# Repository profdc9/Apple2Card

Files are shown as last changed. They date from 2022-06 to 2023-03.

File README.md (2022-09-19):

# Apple II Storage Interface and Arduino Inteface

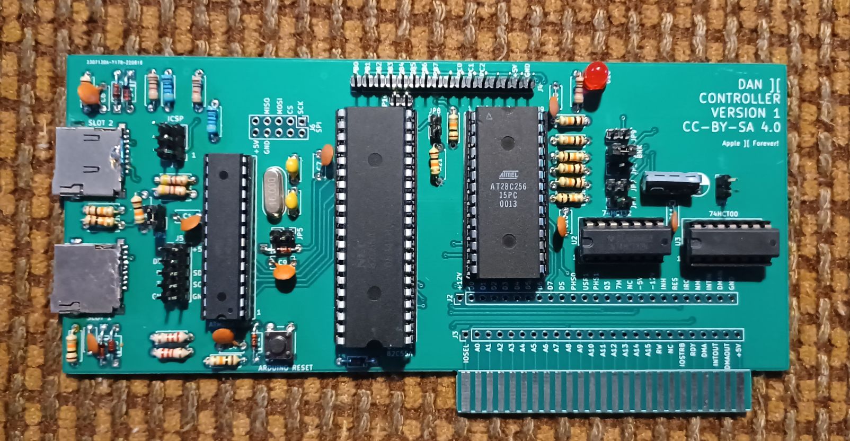
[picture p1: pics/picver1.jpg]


This is a simple card that provides two SD cards as mass storage devices to ProDOS as well as will provide networking using a Wiznet W5500.  A ATMEGA328P programmed using the Arduino development environment is interfaced to the Apple II bus using a 82C55 peripheral interface.  The design uses only five commonly available integrated circuits, the 74HCT08 AND gate, 74HCT32 OR gate, 82C55A peripheral interface, a 28C256 flash memory chip, and a ATMEGA328P microcontroller, and so should be reasonably future-proofed as much as any design for a 40 year old computer can be.

The gerbers for the PCB are in the Apple2Card directly can be made by JLCPCB or PCBway, for example.  The firmware is the "Firmware.bin" file in the Apple2Card directory.  It is a 512 byte file that can be burned onto a 27C128/28C256 flash memory chip using a programmer such as a TL866 plus ii.  Only the first 512 bytes are used of this memory.  The firmware for the ATMEGA328P is the Apple2Arduino sketch in the Apple2Arduino directory.  It should be uploaded using a programmer, however, the bootloader needs to be uploaded first. It should be flashed onto the ATMEGA328P chip without a bootloader.  No SD cards should be present in the SD card slots when the ATMEGA328P is flashed if the ICSP connector on the card is used.  There is a program called FLASH.SYSTEM which can flash the ATMEGA328P on the board.  The jumpers JP2, JP3, JP4, JP6, JP7, JP8, JP9, and JP10 should be closed when flashing with the FLASH.SYSTEM program.  With normal use, all of the jumpers should be open except for JP2 which is closed.

The J1 connector is the ICSP connector for programming the ATMEGA32P.

The J2 and J3 connector break out the bus pins of the Apple II.

The J4 connect are the extra pins of the 82C55 broken out onto a connector.

The J5 connector is for debugging.

The J6 connector is for a Wiznet 5500 SPI ethernet controller (similar to Uthernet).  This has not been implemented yet.

Either micro SD or micro SDHC cards may be used (up to 32 GB capacity), with either FAT16 or FAT32 as the first partition when the FAT filesystem mode is used.  In the raw block mode, only up to the first 512 MB can be used.  To prepare SD cards to be used with storage, you can do it two ways:

The first mode is raw block mode on the SD card.  To use raw block mode, find the "Blankvols.zip" file in the firmware directory.  Unzip this file, and the resulting "Blankvols.PO" file is 512 MB in length.  This can be written to a SD card using an utility such as Win32DiskImager or "dd" under linux.  This is 16 concatenated prepared ProDOS volumes.  Place this in SLOT1 of the card.

The second mode is FAT filesystem mode on the SD card.  A ProDOS order disk image of 32 megabytes can be copied onto the SD card and used.  Such an image is already provided as the file "SingleBlankVol.zip" which is a 32 MB file once unzipped.  Place this file into into the root directory as a file "BLKDEV0X.PO" where X is a digit between 1 and 9.  The default is "1" so for simplicity name it "BLKDEV01.PO".  The ProDOS disk images can be read/written by software such as CiderPress ( https://a2ciderpress.com/ ) so that you can use this to transfer files to and from the Apple II.  Files can be copied onto the ProDOS disk image partition which can then be read/written by CiderPress and transferred to other media.

To make a volume bootable, copy the "PRODOS.SYSTEM" and other system files to be started on booting, for example "BASIC.SYSTEM".

The card can work from any slot, but slot 7 is a good choice so that it can be booted from.  When the card is booted the message "DAN II PRESS RTN" appears on the bottom of the screen.  If the return key is not pressed for a second, then normal booting continues.  The default configuration is to boot the card in SLOT 1 in raw block mode and SLOT 2 in FAT filesystem mode with the filename as "BLKDEV01.PO".

If the return key is pressed during boot up, the following message is shown:

"CARD 1 (0-9,!):"

If in response to this the digit 0 is pressed, the raw block mode is used for SLOT 1.  If digits 1-9 are pressed, FAT filesystem mode is used for SLOT 1, with the filename being "BLKDEV0X.PO" with X being the key pressed.  If ! is pressed, then the mode is wide block mode where both drive 1 and drive 2 of ProDOS are directed to SLOT 1.

Then the next message appears

"CARD 2 (0-9):"

If in response to this the digit 0 is pressed, the raw block mode is used for SLOT 2.  If digits 1-9 are pressed, FAT filsystem mode is used for SLOT 2, with the filename being "BLKDEV0X.PO" with X being the key pressed.  Note that only one of the two slots can be used with FAT filesystem mode at a given time.  If wide block mode is used for CARD 1, then this option does not matter for SLOT 2.

After setting the modes of the two slots, the system continues booting.

Ordinarily, only a maximum of 64 MB is addressable, 32 MB for ProDOS drive 1, and a second 32 MB for ProDOS drive 2.  The program ALLVOLS.SYSTEM allows this limit to be circumvented in ProDOS 8.  For a SD card placed in slot 1, write the image in "BlankVols" or "BlankVolsSlot1"to it, and for a SD card in slot 2, write the image file "BlankVolsSlot2" to it.  When ALLVOLS.SYSTEM is executed, extra volumes may be added from slot 1 or slot 2 depending on if a SD card with block images is present in slot 1 or slot 2.  It is recommended that slot 1 be used for block images and slot 2 be used for FAT FS images.  This way, cards can be swapped in and out of slot 2 with different files transferred from another computer (perhaps using CiderPress) while the boot filesystem in slot 1 stays the same.

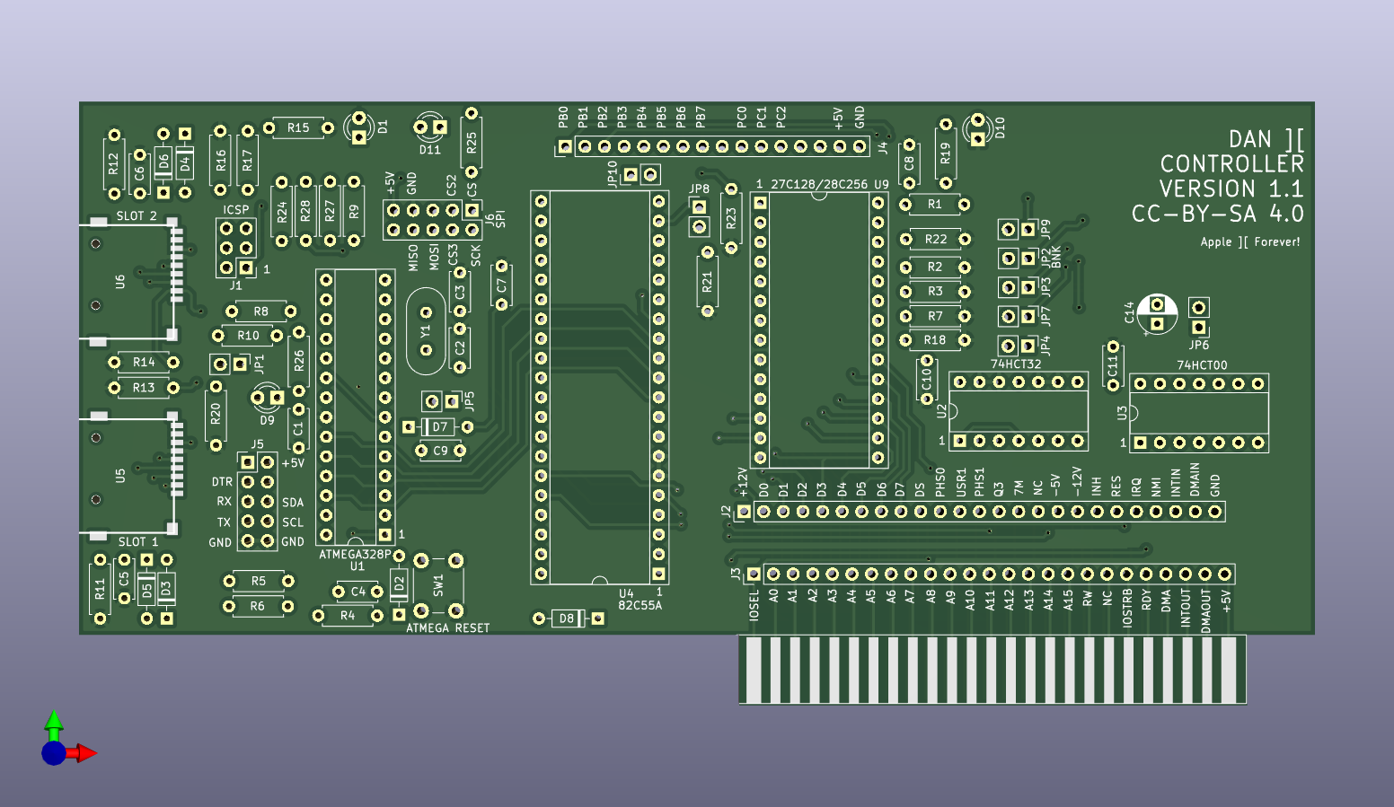
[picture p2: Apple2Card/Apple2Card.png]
Apple2Card


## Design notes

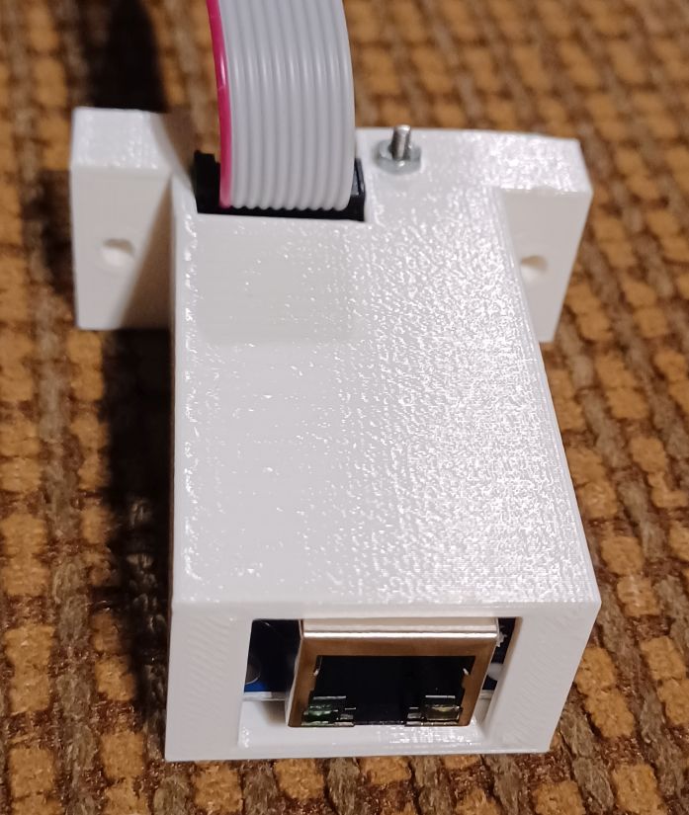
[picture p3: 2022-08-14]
pics/Ethernet-Mount-Front.jpg

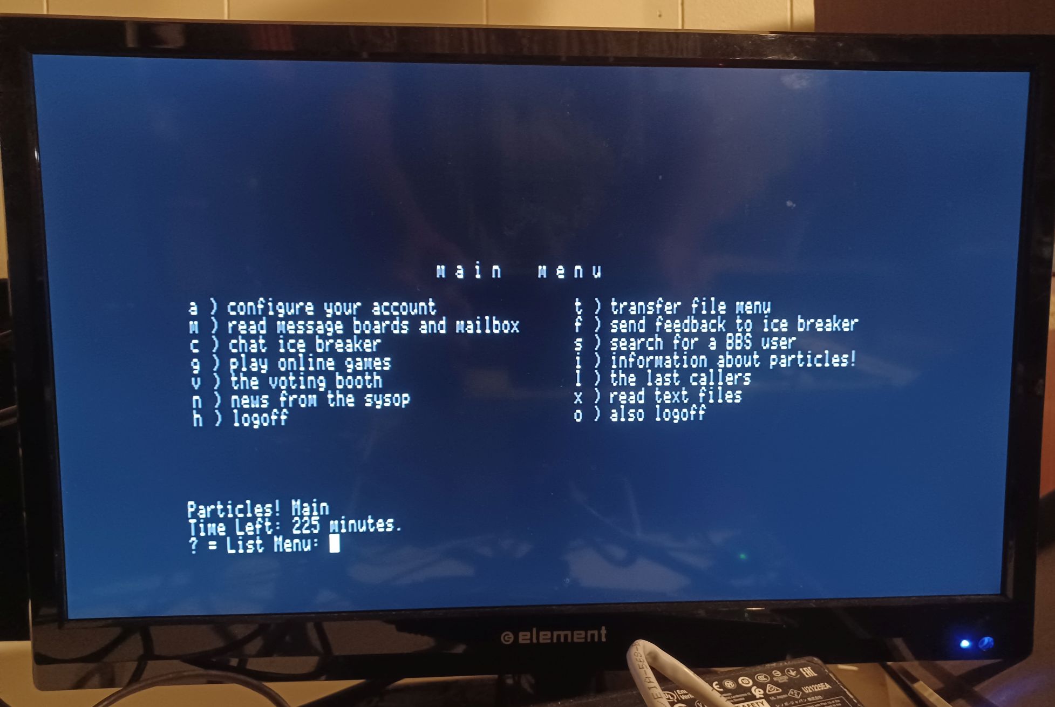
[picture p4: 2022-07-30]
pics/particlesbbs-telnet-example.jpg

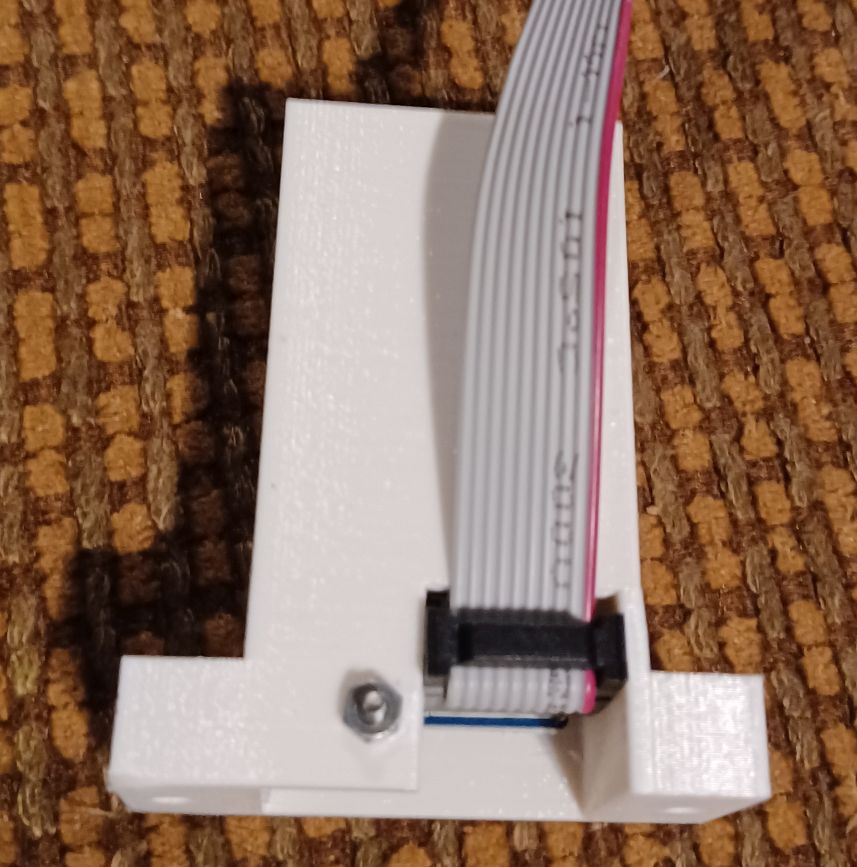
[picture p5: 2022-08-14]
pics/Ethernet-Mount-Back.jpg

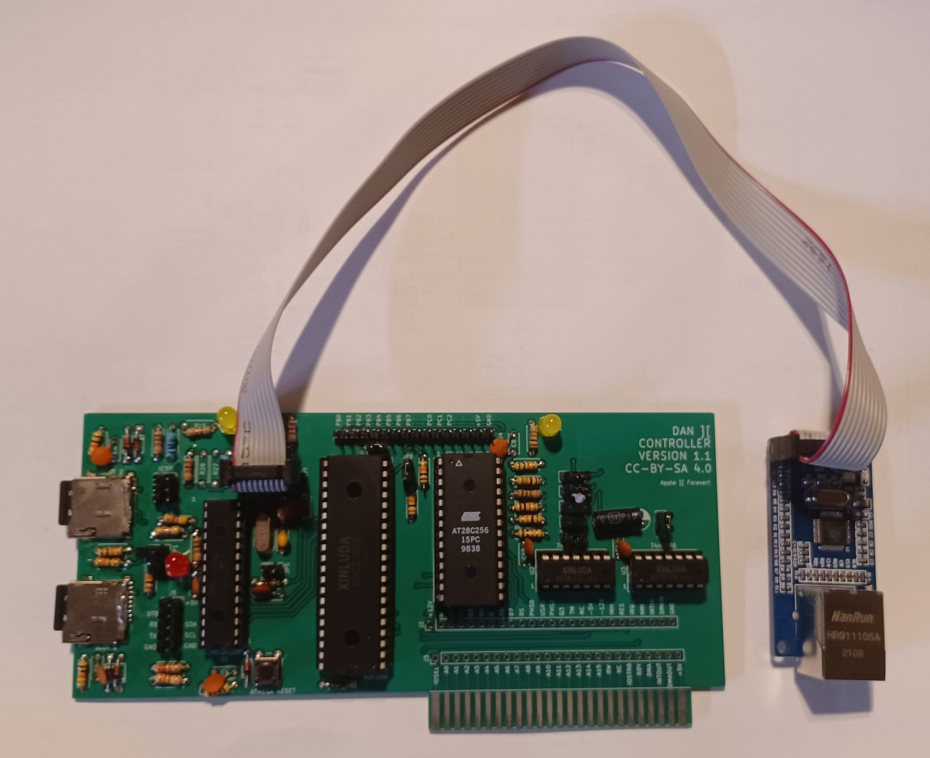
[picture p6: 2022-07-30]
pics/picver11-with-ethernet.jpg

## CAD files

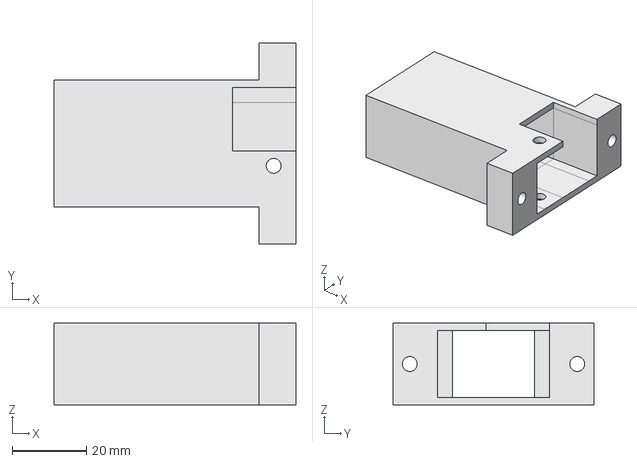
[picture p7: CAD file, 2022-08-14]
CAD/EthernetCover.FCStd
65.0 x 54.0 x 22.0 mm

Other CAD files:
CAD/EthernetCover-EthernetMount.stl

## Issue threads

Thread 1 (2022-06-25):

Build of Materials.

dabonetn, 2022-06-25:
Is there a build of materials with resistor values/sizes, type of sd slot, etc?

profdc9, 2022-06-25:
I have a lcsc.com parts list if you want to look at that.

[ProjectBOM.csv](https://github.com/profdc9/Apple2Card/files/8984833/ProjectBOM.csv)

profdc9, 2022-06-25:
Also here's parts placement
[Parts-Placement.pdf](https://github.com/profdc9/Apple2Card/files/8984834/Parts-Placement.pdf)

dabonetn, 2022-06-30:
I've ordered boards and parts. Hopefully they will show up within a month or so.

msx-solis, 2023-11-29:
Hi,
There are some differences between the current PCB (v1.1) and the schematic, so, even if I generate a new BOM from schematic, fits with your document here but not with the kicad component values on PCB. Witch is the good one?
I mean... I need 2 or 4 x 470R? 3units of 1k or 6 units?
Must we follow what the PCB shows?

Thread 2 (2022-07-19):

Building my first unit, several questions.

dabonetn, 2022-07-19:
Need clarification on some things.

I've got my boards and I've got one nearly built up, and have a few questions.

1. Programming the atmega328p. You say "It should be flashed onto the ATMEGA328P chip without a bootloader. " but the bin file from the audrino output has the name Apple2Arduino.ino.with_bootloader.bin.. Should I just use the hex file named Apple2Arduino.ino.hex??
2. JP2, JP3, JP4 - Should only one of these be selected? What are they actually doing?
3. What jumpers are REQUIRED to run the unit? On the picture I see JP2, JP5 and JP7.
4. What do JP6, JP7, JP8, JP9 and JP10 do? Some seem to control ROM decoding.
5. What are the functions of the LEDs? I think I know, but documentation would be good.
6. Where are the setting stored? On the atmega or the eeprom? (U9)

Thanks!, I'll post more after I get it running over on the vcfed forum.
Keep up the good work.

profdc9, 2022-07-19:
Ok, a number of changes.  I recently revised the board to add some more
functionality.

1.  Program the bootloader first using a programmer.  This sets some fuses
in the ATMEGA328P.  Compile the latest arduino firmware off the project and
upload it using a programmer.  You may need to close JP1 when programming
to power the ATMEGA328P with the programmer if the board is not inside an
apple II when programming.  Make sure there are no SD cards in the slots
whe programming.
2.  The jumpers have changed.  Close jumpers
JP6,JP4,JP7,JP3,JP2,JP9,JP8,JP10.  Then use the "FLASH.SYSTEM" in the
project to flash the firmware onto the FLASH chip.  Then remove the jumpers
except for JP2.  It says this in the "FLASH.SYSTEM" program.
3.  The settings for which drives you are currently using are stored in the
ATMEGA328P EEPROM.  The ROM that the apple ][ sees to boot up is stored in
FLASH rom.
4.  The LEDs are basically convenient access lights to see when the cards
are accessing.  There are two for each card and a third for the planned
network support (W5500).

Dan

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

dabonetn, 2022-07-19:
Is it possible to just program the atmega in the programmer? I've got a tl866 that can handle the chip directly without having to make a programming cable.
I'm also trying to use some standard eproms instead of the eeproms (Out of stock). So what offset does the firmware need to be in the physical chip please. (I have about a 100 27c512s....)

profdc9, 2022-07-19:
You can program the atmega in the programmer but you must set the fuse
values to the standard Arduino fuse values as well as program the firmware.

You can use a 27C512 I believe, as the pinout should be compatible as long
as all the jumpers are open except JP2.  The firmware would be loaded
starting at location zero.

Dan

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

profdc9, 2022-07-19:
Oops, it looks like on the 28C256 the WE line is pin A14 on the 27C512, so
for A14=1, the location to load the firmware at would be $4000, not $0.

Dan

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

dabonetn, 2022-07-20:
Ok, I've got it showing to the apple (Getting the "DAN II PRESS RTN"  prompt).
Using a 8GB generic card that came with one of my 3d printers in slot 2, formatted fat32 and using disk images from www.apple-2.com converted to .po files using cider press, it always breaks to the monitor with

0803-      A=28 X=F8 Y=06 P=35 S=E4.

This is when I select a good disk image number or one that doesn't exist.
I'm slow formatting a 32gb card to try next.

When I tried writing a raw image out with cider press and selecting 0 for the boot, (Card is slot 1), the system just hangs.

profdc9, 2022-07-20:
Format a card FAT32, and then put a 32 MB filesystem on it that is
"BLKDEV01.PO".  Put this card in the lower SD card slot (slot 1).  When you
are booting up, press enter, and then type "1" (for BLKDEV01.PO) for the
first slot, and then choose 0 for the second slot.  Try to see if that
works.

The location it tries to find the image on the card depends on the slot the
card is put into when in mode "0".  This is so many volumes can be accessed
with one card.  The location is at 32 MB X slot number for drive 1, and 32
MB X (slot number + 8) for drive 2.  32 MB = 33554432 bytes exactly.

If you can't get it right, copy the 32 MB file (33554432 byte) file
repeatedly onto the SD card starting at block 0 many times.   If you copy
it 16 times, it will be in all possible locations (all possible slots and
drives).

Dan

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

profdc9, 2022-07-20:
I just tried the original image and the games image from that website, and
they seemed to work ok for e.

Dan

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

dabonetn, 2022-07-20:
I was totally not getting the card 1 and 2 questions.... PLBKAC (Problem lies between keyboard and chair..)

I was trying just slot 2 for the fat32.. I thought slot one was raw sectors.

Just tried 4 of those images and they booted fine.. Total Replay crashes at boot, after displaying the Total Replay text.

Great job.

profdc9, 2022-07-20:
That's weird. I can get Total Replay to work, but only if I boot from
another SD card first, for example, have a mode 0 SD card in slot 1, and
the Replay card in slot 2.

Either slot 1 or slot 2 can be raw sectors which is mode 0 or !  .   If it
is mode 0, the only the slot selected with mode 0 is raw sectors.  If it is
mode ! , both slots are raw sectors from the one SD card that is in SD card
slot 1.  It is possible to assign all of the drivers/sectors to the Dan ][
controller and get over 400 MB in 32 MB volumes.

Dan

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

profdc9, 2022-07-20:
The easy way to do this is to write the Blankvols to a SD card and then
copy the files you want onto the card to make the bootable drive you want.
Blankvols contains 16 consecutive 32 MB filesystems.

Dan

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

dabonetn, 2022-07-20:
""The easy way to do this is to write the Blankvols to a SD card and then
copy the files you want onto the card to make the bootable drive you want.
Blankvols contains 16 consecutive 32 MB filesystems.""

That's a little beyond me, I'm not very experienced with Prodos (Or Apple to be honest.) I was much more of a C64/IBM guy.
How do you boot the other file systems?

Maybe write up a how to? Like start with the most basic instructions and required files and programs?

dabonetn, 2022-07-21:
Ok, another question.. Using both cards, I have images BLKDEV01.PO thtu BLKDEV08.PO files on each.

Booting I select 1 the 2 and boot into a image. (Lets say the booti image), Then if I go into Copy II Plus utils and do a Catalog on slot 7 drive 1, I see the booti drive that I mapped to slot 1, but slot 2 has a read error.

Powering down and swapping cards between the slots results in the same error.

I'm thinking that slot 2 isn't working correctly. Would enabling the debug serial port show any useful information for trouble shooting this?

Thanks, I'm enjoying the learning with this one.

dabonetn, 2022-07-22:
That worked great, now if I only knew how to change partitions using straight prodos on a //e 64k..
Thanks!

profdc9, 2022-07-22:
I'm not sure what you mean with how to change partitions.

It should be possible to change which volumes you are using between boots,
however, I haven't written the program to do that yet...

BTW, Total Replay doesn't seem to have a PRODOS file on it so I don't think
it's bootable in the conventional way.

Dan

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

dabonetn, 2022-07-22:
"" It is possible to assign all of the drivers/sectors to the Dan ][
controller and get over 400 MB in 32 MB volumes""

Ok, by partitions, I meant volumes.. (Sorry, PC guy here..).

"" If ! is pressed, then the mode is wide block mode where both drive 1 and drive 2 of ProDOS are directed to SLOT 1.""

Can you define WIDE block mode better? I used the base BlankVols.po image and put an image in each volume with ciderpress.

profdc9, 2022-07-22:
Ok, so I don't have code to do this yet, but at memory addresses
$BF00-$BFFF (somewhere in there) are the addresses of the driver for each
slot and drive number.  If you choose "0" or "!" and you point the slot and
drive to the driver on the Dan ][ controller, it will use the volume that
is at a given location on the SD card.  So for example, you may not have a
storage device in slot 2, but you could overwrite the address in the table
so that the slot 2 driver goes to the Dan ][ controller and you could get
up to 64 MB (two volumes of 32 MB each for the two drives at that slot)
additional storage.

Yes I know this is not all done yet but honestly even 64 MB is plenty for
most Apple ][ things so it hasn't been a high priority....

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

dabonetn, 2022-07-23:
So I get that I hit ! for wide mode, but for the second question does it matter what you answer for that one?

I'm trying the following sd cards.
4gb
8gb
32gb.

I'm writing out the BlankVols.po image you provided, after I load the partitions.
It always boots the last partition. Either selecting 0 or !.
Selecting ! and a number with no card in slot 2 boots the last partition from the Blankvols.po, and when I hit tab, it lists 7,2
as NEW.DISK.

the 4gb and 8gb were written using Ciderpress.
The 32gb is written using windiskimager.

Doubling up the Blanksvols.po image and writing it to the 32gb still presents NEW.DISK.

dabonetn, 2022-07-27:
Ok, another question for you.

In the wide block mode where both drive 1 and 2 are directed to slot one, where are the boundaries of drives 1 and 2?
I assume since it's block mode, drive 1 starts at sector 0, but how about drive 2?

How many block are presented to the apple when the card is running in block mode per drive?

Thanks.
(p.s. thanks for the quick Total Recall patch!)

profdc9, 2022-07-27:
Sure, when the source of the problem was pointed out it was easy to fix.

The format on the SD card is that each 32 MB volume is a slot and drive, or
65535 blocks + 1 empty block.

The order of the volumes for the first 512 MB of a card:

S0D1 S1D1 S2D1 S3D1 S4D1 S5D1 S6D1 S7D1
S0D2 S1D2 S2D2 S3D2 S4D2 S5D2 S6D2 S7D2

So for example, for S4D2, this would be (11 X 65536 blocks) into the SD
card.

When a "0" mode is used for slot 1, it uses these volumes on the SD card in
slot 1:
S0D1 S1D1 S2D1 S3D1 S4D1 S5D1 S6D1 S7D1

When a "0" mode is used for slot 2, it uses these volumes on the SD card in
slot 2:
S0D2 S1D2 S2D2 S3D2 S4D2 S5D2 S6D2 S7D2

When "!" is used in slot 1, both of the ProDOS drives use slot 1.

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

dabonetn, 2022-07-27:
Ok, I'm now that I'm seeing the layout it making more sense, (like why the S7D1 volume is always the one that boots with the card in slot 7).

But how exactly would you access any slot on the sdcard besides the one that the card is currently in?

I have a test image a test image I wrote out to the card, and I can see S1,S2,S4,S5,S6,and S7 both drives one and two on each, by physically moving the card to the slot number.

This is on a ][e standard 6502, with 64k ram and a old style 80 column card.

I haven't dug out my //gs for testing yet.

profdc9, 2022-07-27:
Well, I plan to make it so that you can copy the driver address to other
slots which don't already have any block devices addressed to them, and
this way you can use the card with many block devices.  I haven't written
the program to do this automatically yet but I have manually tested it.

Dan

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

dabonetn, 2022-07-27:
Ah, ok.

dabonetn, 2022-07-30:
Since all my questions have been answered, I'm closing this.

profdc9, 2022-10-11:
More to the point.... if you look at addresses $BF10-$BF2F in Prodos,
that's where the addresses of the device drivers are.  If you change them
to match the device driver address for the Dan ][, and you have written the
BlankVols.po to the card, it should use the appropriate volume on the card
for the slot and drive.

Dan

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

profdc9, 2022-10-11:
In wide mode,

slot 0 drive 2 starts at sector 8 X 65536 = 524288
slot 1 drive 2 starts at sector 9 X 65536 = 589824
etc...

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

Closed 2022-07-30.

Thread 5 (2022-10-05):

PCB vs schematics: pull-up resistors

ThorstenBr, 2022-10-05:
The PCB wasn't updated when the pull-up resistors were changed from 4k7 to 10k, and from 470 to 4k7 (see commit a848aa25b4dfe19334df68c5f3d26fe0f7ec0768). The current PCB still has the 4k7 / 470 Ohm values. Not a big deal, but a bit confusing. I noticed this since I changed the silk screen of my PCBs to include the component values.

You should update the PCB in KiCad with the latest schematics. Log:

```
Change R3 value from 4k7 to 10k.
Change R18 value from 4k7 to 10k.
Change R2 value from 4k7 to 10k.
Change R21 value from 4k7 to 10k.
Change R22 value from 4k7 to 10k.
Change R28 value from 470R to 4k7.
Change R7 value from 4k7 to 10k.
Change R27 value from 470R to 4k7.
Change R23 value from 4k7 to 10k.
```

ThorstenBr, 2022-10-05:
I created a merge request. You could simply merge this (just the resistor values in the PCB design are updated/changed). Or you can do the update manually (and drop my request).
It's in the KiCad PCB design itself (not the PDF): "Apple2Card.kicad_pcb". If you open the PCB editor to look at the PCB, it was still showing the old resistor values there.

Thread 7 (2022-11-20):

Extended bootloader

ThorstenBr, 2022-11-20:
Hi,
I like the new option to load an extended bootloader from the Arduino flash. We already discussed about this on the Fritter forum. Simply using the existing boot mechanism, and just changing the "Prodos" command is a pretty neat solution.
Are you working on an extended bootloader already or planning to make one?

I did a custom bootloader with a configuration utility for the DAN II card for Apple /// (which did load from an actual boot disk, rather than the DANII controller, since Apple /// doesn't support autoboot ROMs). I could adapt this for the Apple II and make a suggestion (merge request, maybe in a week or two). It could also make use of your new option to read and display the current configuration. Let me know, if you were already working on a bootloader - so I could save the effort.

profdc9, 2022-11-20:
Well, I'm open to having a bootloader written.  Let me explain how it would
have to work and what my idea was, which was very simple.

First what needs to be done.  When you enter the bootloader, the unit
number of the booting device, of which the upper nibble contains the slot
in which it booted from, is in the X register.  Based on this, you can
reconstruct the address of the block routine by using the upper byte as $Cx
where x is the slot number, and the lower byte comes from the location
$CxFF.  You can then store that in the zero page, for example, locations
$F1 (low byte containing contents of $CxFF) and $F2 (high byte containing
$Cx), place the value $20 for the opcode JSR at location $F0, and $60 for
the opcode of RTS at $F3, that way you can JSR $00F0 to call the block
routine.  I have some code below to show how to do this. By the way, I just
changed the "get_status" operation in the Arduino on github, so update
yours before using this code.

My idea for a bootloader was to get the ProDOS volume names of the volume
files on SD slot 1 and SD slot 2 and display them, and then take input for
which was selected.  The ProDOS volume name would serve as the label to
identify the file.

Example code:

INSTRUC = $F0
LOWBT   = $F1
HIGHBT  = $F2
RTSBYT  = $F3
OFFSET  = $F4
VOLDRIVE0 = $F5
VOLDRIVE1 = $F6
BLKBUF = $1000

COMMAND = $42
UNIT    = $43
BUFLO   = $44
BUFHI   = $45
BLKLO   = $46
BLKHI   = $47

START    LDA #$20        ; store JSR at $F0
         STA INSTRUC
         LDA #$60        ; store RTS at $F3
         STA RTSBYT
         STX UNIT        ; store in unit number
         TXA             ; put unit in A register
         LSR A           ; shift to lower nibble
         LSR A
         LSR A
         LSR A
         AND #$07        ; just in case we booted from drive 2 ?
         ORA #$C0        ; make high nibble $C0
         STA HIGHBT      ; store high byte in memory location
         LDY #$00        ; store zero in low byte
         STY LOWBT
         DEY             ; make zero a $FF
         LDA (LOWBT),Y   ; get low byte of address
         STA LOWBT       ; place at low byte
         ...

BUFLOC   LDA #<BLKBUF    ; store buffer location
         STA BUFLO
         LDA #>BLKBUF
         STA BUFHI
         RTS

READB    LDA #$01        ; read block
         STA COMMAND     ; store at $42
         JSR BUFLOC      ; store buffer location
         LDA #$04        ; which block (in this example $0004)
         STA BLKLO
         LDA #$00
         STA BLKHI
         JSR INSTRUC
         RTS

SETVOL   LDA #$06        ; set volume (alternate code)
         STA COMMAND
         JSR BUFLOC      ; dummy buffer location
         LDA VOLDRIVE0
         STA BLKLO
         LDA VOLDRIVE1
         STA BLKHI
         JSR INSTRUC
         RTS

GETVOL   LDA #$05        ; read block
         STA COMMAND     ; store at $42
         JSR BUFLOC      ; store buffer location
         JSR INSTRUC
         LDA BLKBUF
         STA VOLDRIVE0
         LDA BLKBUF+1
         STA VOLDRIVE1
         RTS

REBOOT   LDA #$00        ; store zero byte at $F1
         STA LOWBT
         JMP (LOWBT)     ; jump back and reboot

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

ThorstenBr, 2022-11-21:
Concerning detecting the slot via the X-register: I already had a look into this. Right now, it wouldn't work, since the value of X is lost before the ROM jumps to the bootloader. It always resets X before returning to the caller (or jumping to the bootloader):

```
quitok:
    ldx  unit    ; <<== causes X to be lost prior to "RTS"
    lda  #$00
    clc
    rts
```
The "ldx unit" is probably only required when returning to Prodos, but the same code is executed before jumping to the bootloader. So right now, a bootloader has no way to tell from where it was loaded.

One solution I thought about was making a change to the readbytes routine:
```
@@ -179,8 +179,8 @@ readbytes:
     bne  readbytes   ; get next byte to 256 bytes
     ldy  uppage
     bne  exit512     ; already read upper page
+    stx  uppage      ; store x!=0 to indicate we're processing the second page
     inc  bufhi
-    inc  uppage
     bne  readbytes
```
X is always != 0, so it can be used as a flag to indicate when readbytes is processing the second page (instead of "inc uppage"). As a side effect, the scratch register "uppage" then retains the X value indicating the slot when the bootloader is executed. Tiny change, wouldn't even cost an extra byte.

Ok, I'll be looking into the bootloader. I'll push something to my GitHub when I have a first working version, so you can have a look.

ThorstenBr, 2022-11-21:
Thanks for the hint with the X register and "unit" containing the slot information in the top nibble. I had already looked at that - and initially thought that unit was zero at boot time. So identifying the slot is actually easier than I initially thought.

Ok, I'll be looking into the bootloader. I'll push something to my GitHub when I have a first working version, so you can have a look.

profdc9, 2022-11-22:
I was intending that the unit number would be used to reconstruct the slot
number.  So that for example, if the card was booted from slot 7, unit
number would be $70.  This could be used to reconstruct the address of the
ProDOS block driver routine in $C7xx (where xx is at the location $C7FF).
The code fragment I sent shows how I thought this might be done, so the
code would be consistent with how the bootloader uses the X register.

Dan

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

Closed 2022-11-23.

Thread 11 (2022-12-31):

A2osX Ethernet Driver

burniouf, 2022-12-31:
Where could i find documentation to add an ETH driver to support this board ?

https://github.com/A2osX/A2osX

actually supporting, U1, U2, LANCEGS, SSC/PPP...

https://github.com/A2osX/A2osX/tree/master/DRV

profdc9, 2023-01-01:
Support for ethernet on this board has already been implement on IP65.  It is based on plugging a W5500 Wiznet module into the board via SPI into the ATMEGA328P.  A picture of the board with the ethernet module attached:

https://github.com/profdc9/Apple2Card/blob/main/pics/picver11-with-ethernet.jpg

This is a commonly available W5500 ethernet module.  The IP65 version patched to use the Dan ][ controller with W5500 attached is here:

https://github.com/profdc9/ip65

The file that shows how to communicate with the ATMEGA328P to exchange packets is this one:

https://github.com/profdc9/ip65/blob/main/drivers/dan2d.s

It is pretty simple, as most of the logic to actually control the W5500 is implemented by the ATMEGA328P.   You can ignore the stuff for "ATARI" as it doesn't really apply here.

A command is sending bytes to the 82C55 port A (wrbt) and receiving them (rdbt).

Initialize:
$AC,$10,$XX,$XX,$XX,$XX,$XX,$XX (six bytes of MAC addr to initialize W5500)
receive $00 as confirmation

Poll: (read packet)
$AC,$11,<packet buf size low>,<packet buf size high>
Receive two bytes which is length of packet.  If $00 $00, no packet is available.
Otherwise is low byte, high byte of length of packet
Then receive that number of bytes as the packet

Send:(transmit packet)
$AC,$12,<packet size low>,<packet size high>
Send exact number of packet bytes
Read one byte of result, zero if no error

Hopefully that will get you started.

burniouf, 2023-01-02:
Ok, Perfect! i can quickly write something...
as i have no HW yet to test, could you send me one of your team able to test at :

https://join.slack.com/t/a2osx/shared_invite/zt-ens62cl0-xeAFLjlRfUSMtzdc6o~Xew

is Dan2eth.drv a proper name for this driver ?

profdc9, 2023-01-02:
Dan2eth.drv is just fine as a name for the driver.

profdc9, 2023-01-02:
I don't have any spare cards right now, but I could build one up.  I am
quite busy right now so it might be a little while.  You could get them
faster because there is someone selling them on ebay out of Ireland:

https://www.ebay.com/itm/125663287867

You will also need a W5500 card, this one (available from many vendors):

https://www.ebay.com/itm/311590216566

And a 10 pin IDC (2 rows X 5) 2.54 mm pitch cable to connect the two.

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

burniouf, 2023-01-02:
Ok, thanks... maybe i will order from that guy....

i m almost done writing the DRV.

Any "CLOSE" or "SHUTDOWN" command ?
Any way to get Link Status and 10/100 or HD/FD ?

if someone can test, i will probably get it done today or tomorrow....

burniouf, 2023-01-02:
I would also need a way to detect if WIZ is plugged in....or not....for auto-detection routine.

profdc9, 2023-01-02:
When the initialization occurs, if you do not get a $00, there is an error
initializing.

I don't at present have any close or shutdown commands or link status, I
only implemented what is needed for IP65.

I could look into adding these if it is necessary for A2osX.

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

burniouf, 2023-01-02:
it is not mandatory, but other drivers are written like this :
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

burniouf, 2023-01-02:
DRV done....
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
meet me at SLACK if you want a TEST media

Daniel102010, 2023-01-02:
Hi, I’m Daniel from Ireland , Happy New Year!!! I seen “you’re talking about me “ 😉 if you need one or more Dan II cards you can always contact me directly at ***@***.*** for a better price. Regards Daniel 

Sent from Yahoo Mail for iPhone

On Monday, January 2, 2023, 3:23 p.m., Rémy GIBERT ***@***.***> wrote:

DRV done....

meet me at SLACK if you want a TEST media

—
Reply to this email directly, view it on GitHub, or unsubscribe.
You are receiving this because you are subscribed to this thread.Message ID: ***@***.***>

burniouf, 2023-01-02:
Sure !!

Happy new year!!!

i will contact you at  ***@***.*** with no delay ;-)

Remy

burniouf, 2023-01-04:
Guys, any chance i get a test report about code submitted to Daniel Marks at our SLACK place ?

profdc9, 2023-01-06:
Sorry, I have been very busy the past few days.

I was working on getting the AosX you sent me working.  Unfortunately I can
not use the 800k image you send as I do not have a drive emulator.  It
would be easier if you could send me a zipped 32 MB image file with the
driver to test on it.

Also, having nothing to do with your code, I need to get my wireless
gateway to work in my new location so I can test the ethernet, which I
haven't been able to do yet.  It just won't connect to by router, I need to
figure this out.

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

burniouf, 2023-01-06:
ZIP file & instructions to use it posted at SLACK. enjoy.

profdc9, 2023-01-06:
By the way, how does AosX figure out which slot the Dan ][ card is in?
Does it look for a signature of the ROM?

Dan

On Fri, Jan 6, 2023 at 12:45 AM Rémy GIBERT ***@***.***>
wrote:

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

Micheledipaola, 2023-02-20:
Hey @burniouf and @profdc9 , I have a card assembled by @Daniel102010 and I am very curious about the A2osX driver, since I am waiting for a W5500 module from China. Is it available somewhere? I am wondering also if building a driver for the IIGS could be complicated...

burniouf, 2023-02-20:
hoy @Micheledipaola !
dan2eth.drv Driver is included in most of available A2osX STABLE medias.
An timing issue *may* be still present when running A2osX on IIgs with this driver....still awaiting test reports....
About driver for other TCP/IP stacks, feel free to get the code from A2osX, and of course you can point any other developer to A2osX team if additional information required about supporting this W5500 eth device.

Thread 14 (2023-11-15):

Disk drive still seems to be default device even after image boot

rittwage, 2023-11-15:
I have a weird issue I've noticed with the Dan][.

I have a ProDOS 2.4 image that I've installed GSOS 6.01 on, and it boots into Bitsy.bye normally (I modified the startup to this instead of GSOS/ProDOS). The ProDOS file is renamed to GSOS.

This works fine on my old CF card controller, and on emulators. It boots into Bitsy.Bye and I can choose to boot GSOS or BASIC, or whatever.  However, on the Dan][, it gets an error $002F when you try to boot GSOS.

The weird thing is, if you have a floppy with GSOS in the 3.5 drive, it will boot when you choose the GSOS file on the hard drive.  So, it seems something is pointing the system at the floppy drive instead of the Dan][ partition?

 Card is in slot 7.

The old Apple2.com hard drive image assembled by Vince Briel a while back has a similar problem when booting.

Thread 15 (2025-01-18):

Confusion of the Atmega firmware

coopzone-dc, 2025-01-18:
I have read the README file and just can't work out if I need a chip with the Arduino boot loader installed or not!

It refers to a bootloader install first, but is this the "normal" atmega boot loader, that allows serial upload of the sketch? or what?

What is the correct procedure to put the sketch on the atmega328

Thanks

Derek

profdc9, 2025-01-18:
You can use a chip with the normal bootloader but it is not required.  What
is required is to program the MEGA with the same fuse settings that the
bootloader uses (16 MHz etc.) which I don't remember off the top of my
head, but if you program the bootloader it programs the fuse settings as
well.

Dan

On Sat, Jan 18, 2025 at 10:25 AM coopzone-dc ***@***.***>
wrote:

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

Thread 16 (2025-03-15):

Unable to get the card to work with SD-Card on board

coopzone-dc, 2025-03-15:
Hello,

I have tried all I can think of. I suspect it's a power related problem or a logic level conversion issue.

For example I measured the SD-Card slot voltage at around 3.9v with the two 1n4148's any sd card I try fails 90%+ of the time the other 10% it's very unreliable. I added a 3.3v regulator this helped a little, still fails most of the time.

I have not yet tried different values for the divider resistors 5v to 3.3v conversion. I got side tracked trying a different idea.

I have currently got two SD-Card Arduino mini PCB adaptors connected directly to the atbmega328p. These boards have on board 3.3v regulation and level converters. And They Work!

With these SD-card adaptors I can use the card just fine, once it's been reset CRTL-APPLE-Reset.

The first time you turn the machine on, it still fails and ends up in the Apple monitor. After the press return prompt. At this point if I reset without power off it works fine and keeps working fine until the next power cycle.

I'm happy to use the cards as they work so well. But I was hoping to get, maybe a new version on the sorftware ROM or Atmega with perhaps a delay on power up or an extra reset or something that will stop it failing when powered on?

Has anyone else seen similar issues?

Thanks

Derek

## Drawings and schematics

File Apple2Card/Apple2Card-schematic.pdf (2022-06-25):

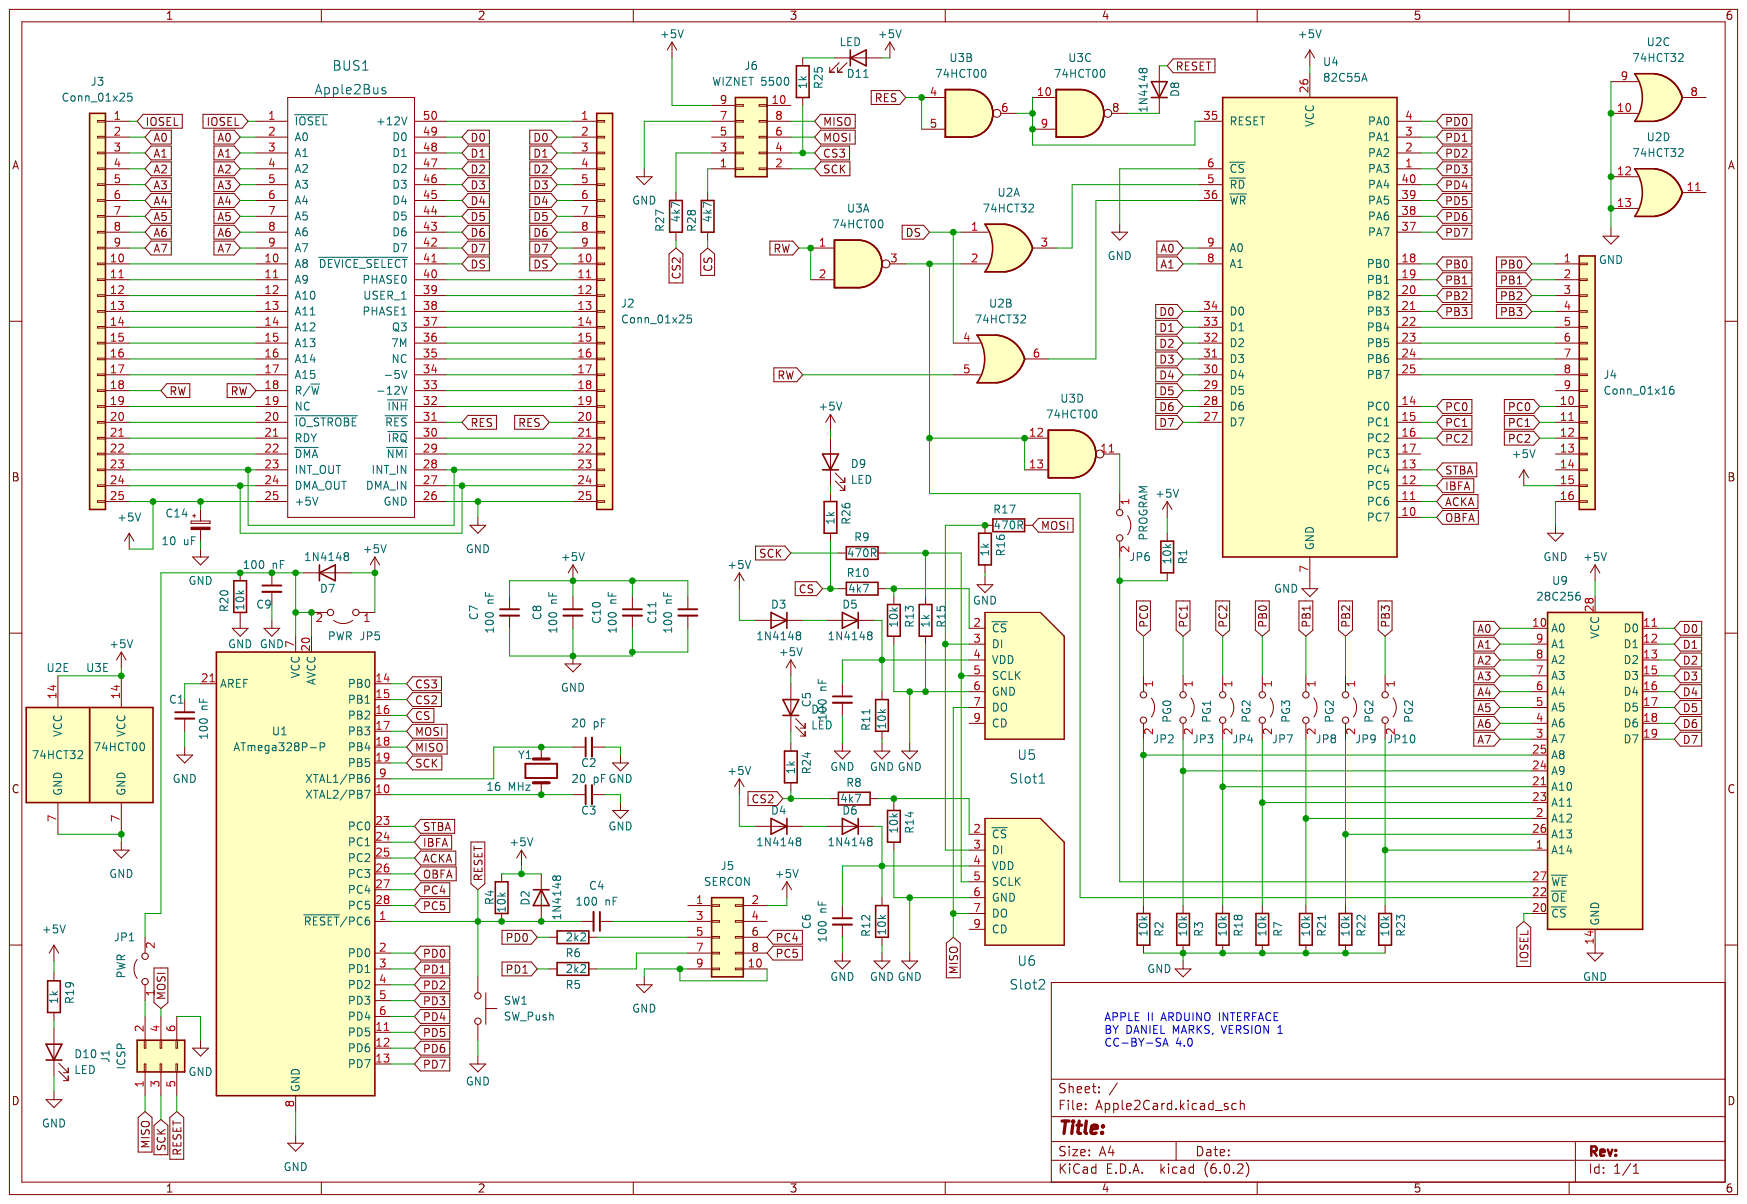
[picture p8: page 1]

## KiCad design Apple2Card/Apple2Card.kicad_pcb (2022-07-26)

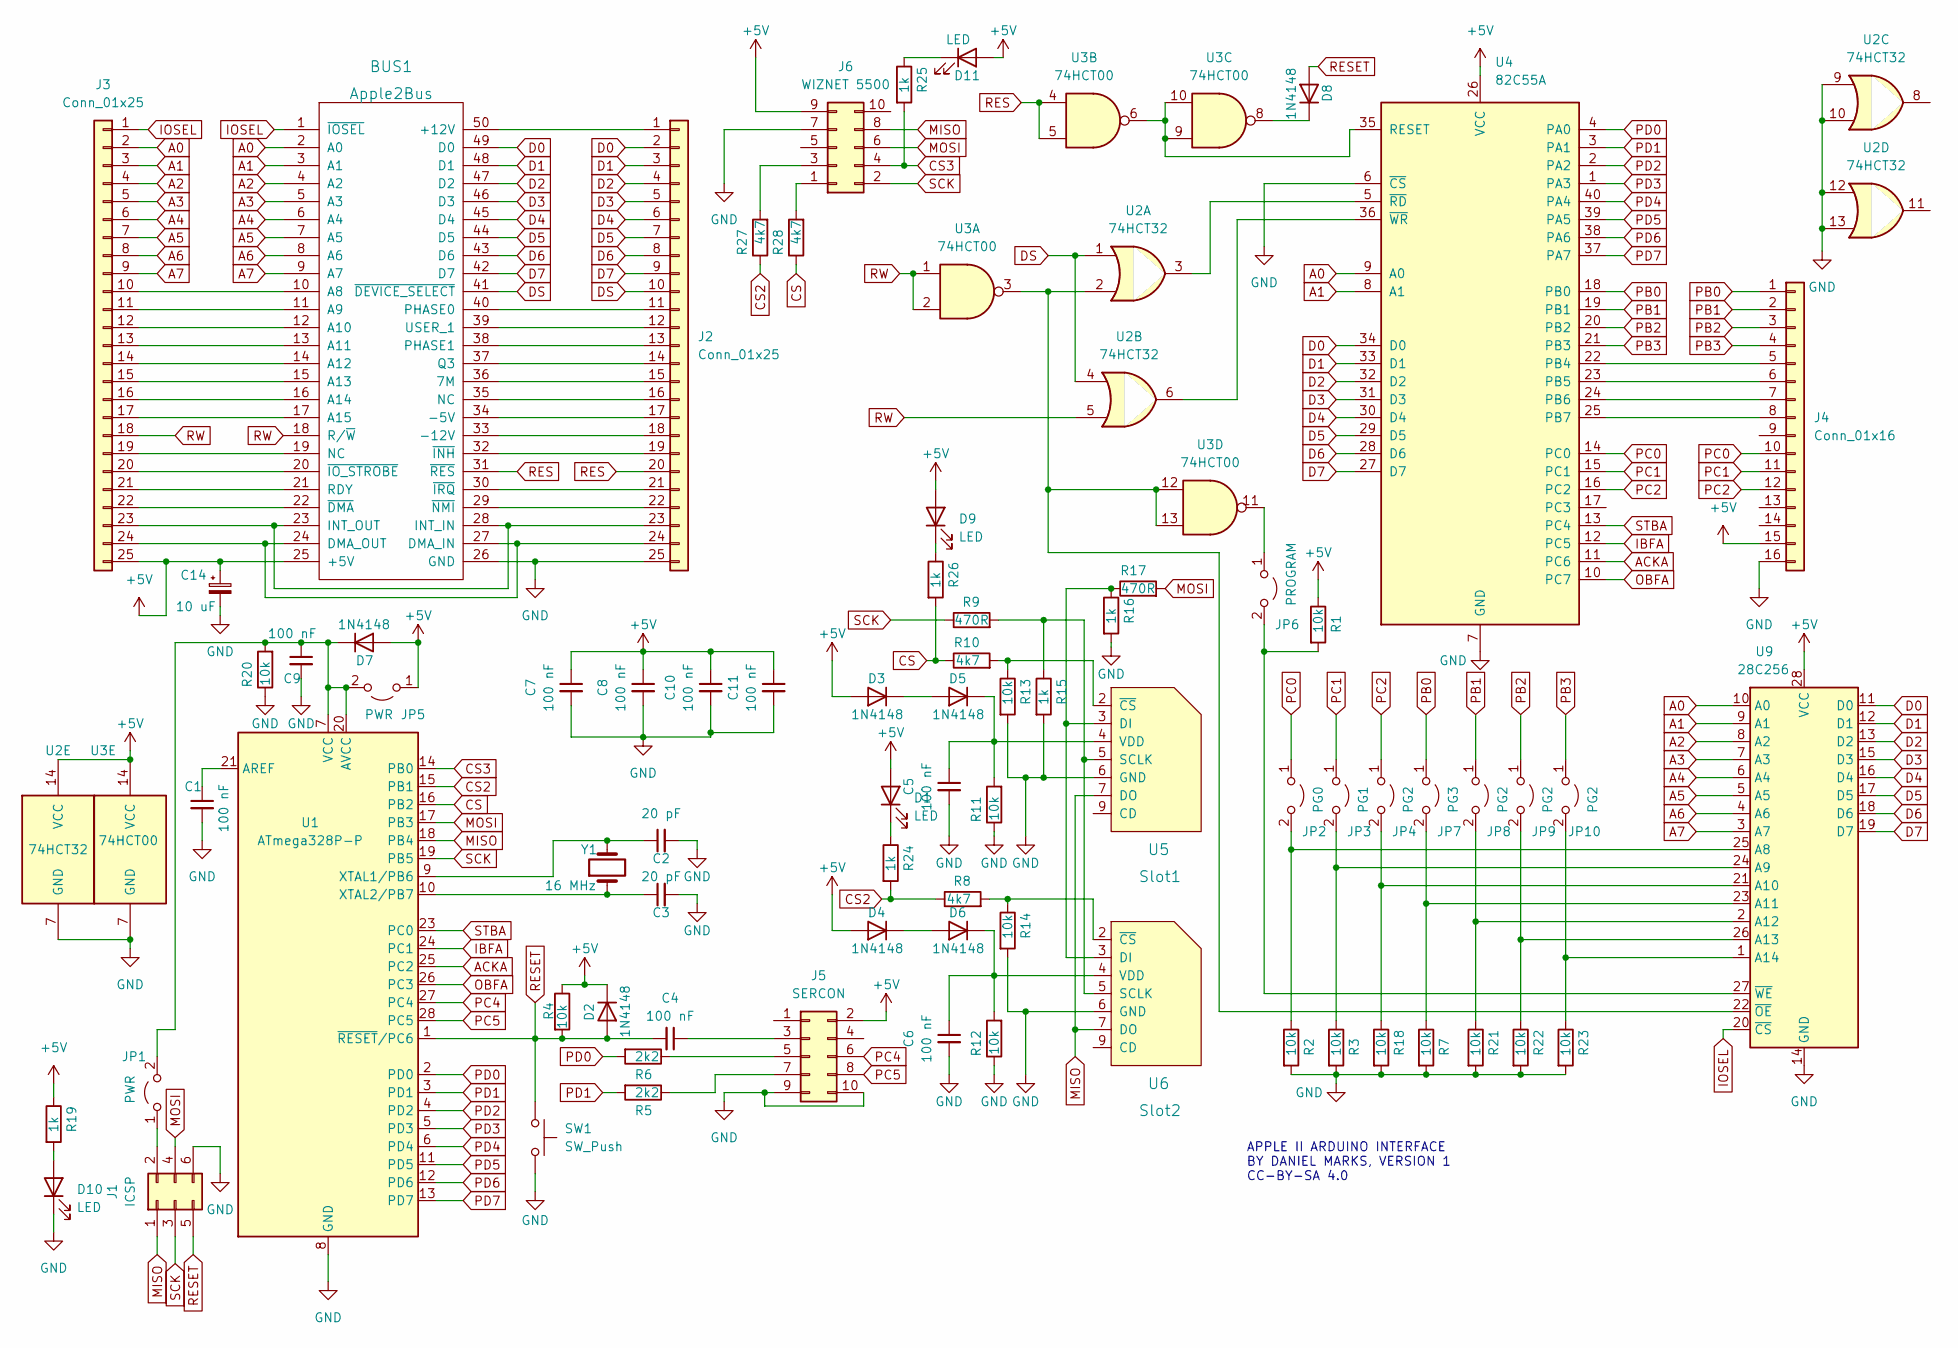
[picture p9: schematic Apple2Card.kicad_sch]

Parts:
BUS1: Apple2Bus; Apple2Slot
C1, C4, C5, C6, C7, C8, C9, C10, C11: 100 nF; C_Disc_D5.0mm_W2.5mm_P5.00mm
C2, C3: 20 pF; C_Disc_D5.0mm_W2.5mm_P5.00mm
C14: 10 uF; CP_Radial_D5.0mm_P2.50mm
D1, D9, D10, D11: LED; LED_D3.0mm
D2, D3, D4, D5, D6, D7, D8: 1N4148; D_DO-35_SOD27_P7.62mm_Horizontal
J1: ICSP; PinHeader_2x03_P2.54mm_Vertical
J2, J3: Conn_01x25; PinHeader_1x25_P2.54mm_Vertical
J4: Conn_01x16; PinHeader_1x16_P2.54mm_Vertical
J5: SERCON; PinHeader_2x05_P2.54mm_Vertical
J6: WIZNET 5500; PinHeader_2x05_P2.54mm_Vertical
JP1, JP5: PWR; PinHeader_1x02_P2.54mm_Vertical
JP2: PG0; PinHeader_1x02_P2.54mm_Vertical
JP3: PG1; PinHeader_1x02_P2.54mm_Vertical
JP4, JP8, JP9, JP10: PG2; PinHeader_1x02_P2.54mm_Vertical
JP6: PROGRAM; PinHeader_1x02_P2.54mm_Vertical
JP7: PG3; PinHeader_1x02_P2.54mm_Vertical
R1, R2, R3, R4, R7, R11, R12, R13, R14, R18, R20, R21, R22, R23: 10k; R_Axial_DIN0207_L6.3mm_D2.5mm_P7.62mm_Horizontal
R5, R6: 2k2; R_Axial_DIN0207_L6.3mm_D2.5mm_P7.62mm_Horizontal
R8, R10, R27, R28: 4k7; R_Axial_DIN0207_L6.3mm_D2.5mm_P7.62mm_Horizontal
R9, R17: 470R; R_Axial_DIN0207_L6.3mm_D2.5mm_P7.62mm_Horizontal
R15, R16, R19, R24, R25, R26: 1k; R_Axial_DIN0207_L6.3mm_D2.5mm_P7.62mm_Horizontal
SW1: SW_Push; SW_PUSH_6mm
U1: ATmega328P-P; DIP-28_W7.62mm_Socket
U2: 74HCT32; DIP-14_W7.62mm_Socket
U3: 74HCT00; DIP-14_W7.62mm_Socket
U4: 82C55A; DIP-40_W15.24mm_Socket
U5: Slot1; GCT-MEM2055-00-190-01-A
U6: Slot2; GCT-MEM2055-00-190-01-A
U9: 28C256; DIP-28_W15.24mm_Socket
Y1: 16 MHz; Crystal_HC49-U_Vertical

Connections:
+5V: BUS1.25 (+5V), C7.1, C8.1, C10.1, C11.1, C14.1, D1.2 (A), D2.1 (K), D3.2 (A), D4.2 (A), D7.2 (A), D9.2 (A), D11.2 (A), J3.25, J4.15, J5.2, J6.9, JP5.1 (A), R1.1, R4.1, R19.1, U2.14 (VCC), U3.14 (VCC), U4.26 (VCC), U9.28 (VCC)
A0: BUS1.2 (A0), J3.2, U4.9 (A0), U9.10 (A0)
A1: BUS1.3 (A1), J3.3, U4.8 (A1), U9.9 (A1)
A2: BUS1.4 (A2), J3.4, U9.8 (A2)
A3: BUS1.5 (A3), J3.5, U9.7 (A3)
A4: BUS1.6 (A4), J3.6, U9.6 (A4)
A5: BUS1.7 (A5), J3.7, U9.5 (A5)
A6: BUS1.8 (A6), J3.8, U9.4 (A6)
A7: BUS1.9 (A7), J3.9, U9.3 (A7)
ACKA: U1.25 (PC2), U4.11 (PC6)
CS: R10.1, R26.2, R28.1, U1.16 (PB2)
CS2: R8.1, R24.2, R27.1, U1.15 (PB1)
CS3: J6.4, R25.2, U1.14 (PB0)
D0: BUS1.49 (D0), J2.2, U4.34 (D0), U9.11 (D0)
D1: BUS1.48 (D1), J2.3, U4.33 (D1), U9.12 (D1)
D2: BUS1.47 (D2), J2.4, U4.32 (D2), U9.13 (D2)
D3: BUS1.46 (D3), J2.5, U4.31 (D3), U9.15 (D3)
D4: BUS1.45 (D4), J2.6, U4.30 (D4), U9.16 (D4)
D5: BUS1.44 (D5), J2.7, U4.29 (D5), U9.17 (D5)
D6: BUS1.43 (D6), J2.8, U4.28 (D6), U9.18 (D6)
D7: BUS1.42 (D7), J2.9, U4.27 (D7), U9.19 (D7)
DS: BUS1.41 (~DEVICE_SELECT), J2.10, U2.1, U2.4
GND: BUS1.26 (GND), C1.2, C2.2, C3.2, C5.2, C6.2, C7.2, C8.2, C9.2, C10.2, C11.2, C14.2, D10.1 (K), J1.6, J2.25, J4.16, J5.9, J5.10, J6.7, R2.2, R3.2, R7.2, R11.1, R12.1, R13.2, R14.2, R15.2, R16.2, R18.2, R20.1, R21.2, R22.2, R23.2, SW1.2, U1.8 (GND), U1.22 (GND), U2.7 (GND), U2.9, U2.10, U2.12, U2.13, U3.7 (GND), U4.6 (~CS), U4.7 (GND), U5.6 (GND), U6.6 (GND), U9.14 (GND)
IBFA: U1.24 (PC1), U4.12 (PC5)
IOSEL: BUS1.1 (~IOSEL), J3.1, U9.20 (~CS)
MISO: J1.1, J6.8, U1.18 (PB4), U5.7 (DO), U6.7 (DO)
MOSI: J1.4, J6.6, R17.2, U1.17 (PB3)
unnamed: BUS1.10 (A8), J3.10
unnamed: BUS1.11 (A9), J3.11
unnamed: BUS1.12 (A10), J3.12
unnamed: BUS1.13 (A11), J3.13
unnamed: BUS1.14 (A12), J3.14
unnamed: BUS1.15 (A13), J3.15
unnamed: BUS1.16 (A14), J3.16
unnamed: BUS1.17 (A15), J3.17
unnamed: BUS1.19 (NC), J3.19
unnamed: BUS1.20 (~IO_STROBE), J3.20
unnamed: BUS1.21 (RDY), J3.21
unnamed: BUS1.22 (~DMA), J3.22
unnamed: BUS1.23 (INT_OUT), BUS1.28 (INT_IN), J2.23, J3.23
unnamed: BUS1.24 (DMA_OUT), BUS1.27 (DMA_IN), J2.24, J3.24
unnamed: BUS1.29 (~NMI), J2.22
unnamed: BUS1.30 (~IRQ), J2.21
unnamed: BUS1.32 (~INH), J2.19
unnamed: BUS1.33 (-12V), J2.18
unnamed: BUS1.34 (-5V), J2.17
unnamed: BUS1.35 (NC), J2.16
unnamed: BUS1.36 (7M), J2.15
unnamed: BUS1.37 (Q3), J2.14
unnamed: BUS1.38 (PHASE1), J2.13
unnamed: BUS1.39 (USER_1), J2.12
unnamed: BUS1.40 (PHASE0), J2.11
unnamed: BUS1.50 (+12V), J2.1
unnamed: C1.1, U1.21 (AREF)
unnamed: C2.1, U1.9 (XTAL1/PB6), Y1.2
unnamed: C3.1, U1.10 (XTAL2/PB7), Y1.1
unnamed: C4.1, J5.3
unnamed: C5.1, D5.1 (K), R11.2, U5.4 (VDD)
unnamed: C6.1, D6.1 (K), R12.2, U6.4 (VDD)
unnamed: C9.1, D7.1 (K), JP1.2 (B), JP5.2 (B), R20.2, U1.7 (VCC), U1.20 (AVCC)
unnamed: D1.1 (K), R24.1
unnamed: D3.1 (K), D5.2 (A)
unnamed: D4.1 (K), D6.2 (A)
unnamed: D8.1 (K), U3.8
unnamed: D9.1 (K), R26.1
unnamed: D10.2 (A), R19.2
unnamed: D11.1 (K), R25.1
unnamed: J1.2, JP1.1 (A)
unnamed: J4.5, U4.22 (PB4)
unnamed: J4.6, U4.23 (PB5)
unnamed: J4.7, U4.24 (PB6)
unnamed: J4.8, U4.25 (PB7)
unnamed: J5.5, R6.1
unnamed: J5.7, R5.1
unnamed: J6.1, R28.2
unnamed: J6.3, R27.2
unnamed: JP2.2 (B), R2.1, U9.25 (A8)
unnamed: JP3.2 (B), R3.1, U9.24 (A9)
unnamed: JP4.2 (B), R18.1, U9.21 (A10)
unnamed: JP6.1 (A), U3.11
unnamed: JP6.2 (B), R1.2, U9.27 (~WE)
unnamed: JP7.2 (B), R7.1, U9.23 (A11)
unnamed: JP8.2 (B), R21.1, U9.2 (A12)
unnamed: JP9.2 (B), R22.1, U9.26 (A13)
unnamed: JP10.2 (B), R23.1, U9.1 (A14)
unnamed: R10.2, R13.1, U5.2 (~CS)
unnamed: R8.2, R14.1, U6.2 (~CS)
unnamed: R9.2, R15.1, U5.5 (SCLK), U6.5 (SCLK)
unnamed: R16.1, R17.1, U5.3 (DI), U6.3 (DI)
unnamed: U2.2, U3.3, U3.12, U3.13, U9.22 (~OE)
unnamed: U2.3, U4.5 (~RD)
unnamed: U2.6, U4.36 (~WR)
unnamed: U3.6, U3.9, U3.10, U4.35 (RESET)
OBFA: U1.26 (PC3), U4.10 (PC7)
PB0: J4.1, JP7.1 (A), U4.18 (PB0)
PB1: J4.2, JP8.1 (A), U4.19 (PB1)
PB2: J4.3, JP9.1 (A), U4.20 (PB2)
PB3: J4.4, JP10.1 (A), U4.21 (PB3)
PC0: J4.10, JP2.1 (A), U4.14 (PC0)
PC1: J4.11, JP3.1 (A), U4.15 (PC1)
PC2: J4.12, JP4.1 (A), U4.16 (PC2)
PC4: J5.6, U1.27 (PC4)
PC5: J5.8, U1.28 (PC5)
PD0: R6.2, U1.2 (PD0), U4.4 (PA0)
PD1: R5.2, U1.3 (PD1), U4.3 (PA1)
PD2: U1.4 (PD2), U4.2 (PA2)
PD3: U1.5 (PD3), U4.1 (PA3)
PD4: U1.6 (PD4), U4.40 (PA4)
PD5: U1.11 (PD5), U4.39 (PA5)
PD6: U1.12 (PD6), U4.38 (PA6)
PD7: U1.13 (PD7), U4.37 (PA7)
RES: BUS1.31 (~RES), J2.20, U3.4, U3.5
RESET: C4.2, D2.2 (A), D8.2 (A), J1.5, R4.2, SW1.1, U1.1 (~RESET/PC6)
RW: BUS1.18 (R/~W), J3.18, U2.5, U3.1, U3.2
SCK: J1.3, J6.2, R9.1, U1.19 (PB5)
STBA: U1.23 (PC0), U4.13 (PC4)

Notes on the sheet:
APPLE II ARDUINO INTERFACE BY DANIEL MARKS, VERSION 1 CC-BY-SA 4.0

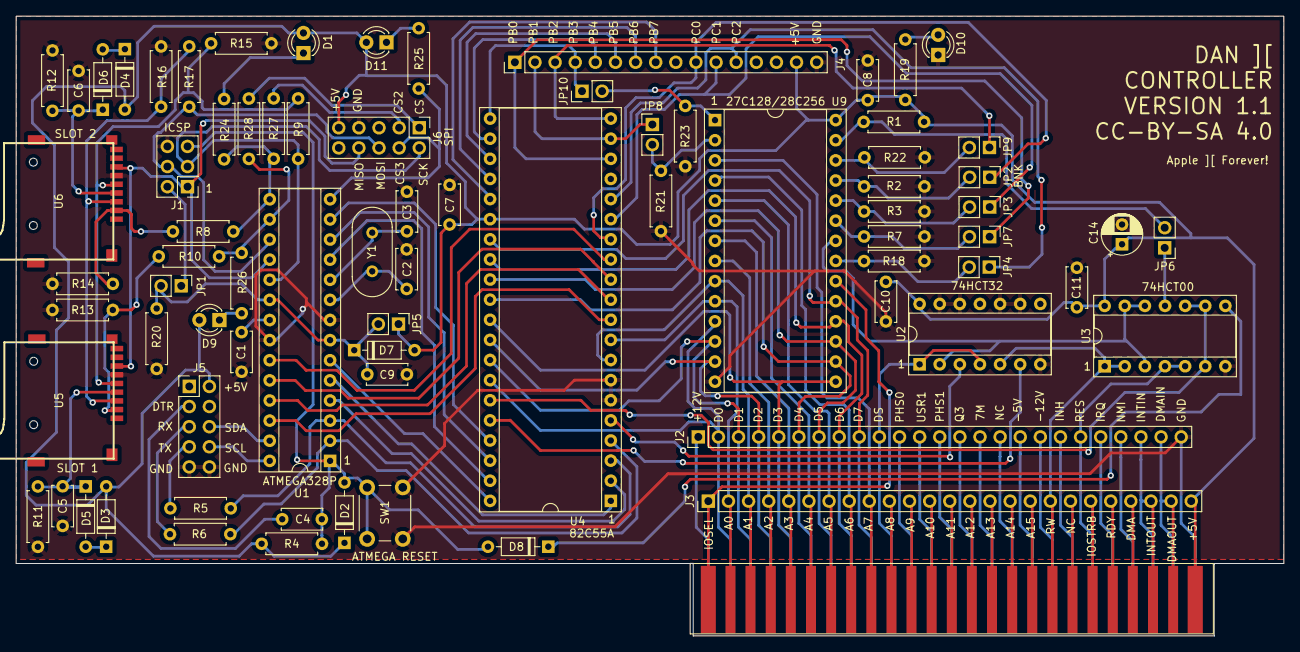
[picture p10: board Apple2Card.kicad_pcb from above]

Board: 2 copper layers, 160.0 x 78.2 mm, 77 parts (0 on the bottom side), 116 nets.

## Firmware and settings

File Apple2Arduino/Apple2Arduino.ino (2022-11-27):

/* Apple2Arduino firmware */
/* by Daniel L. Marks */

/*
   Copyright (c) 2022 Daniel Marks

  This software is provided 'as-is', without any express or implied
  warranty. In no event will the authors be held liable for any damages
  arising from the use of this software.

  Permission is granted to anyone to use this software for any purpose,
  including commercial applications, and to alter it and redistribute it
  freely, subject to the following restrictions:

  1. The origin of this software must not be misrepresented; you must not
   claim that you wrote the original software. If you use this software
   in a product, an acknowledgment in the product documentation would be
   appreciated but is not required.
  2. Altered source versions must be plainly marked as such, and must not be
   misrepresented as being the original software.
  3. This notice may not be removed or altered from any source distribution.
*/

/* Note to self to create objdump:

  C:\Users\dmarks\Documents\ArduinoData\packages\arduino\tools\avr-gcc\4.8.1-arduino5\bin\avr-objdump.exe -x -t -s Apple2Arduino.ino.elf > s155143
*/

#include <Arduino.h>
#include <avr/pgmspace.h>
#include <EEPROM.h>
#include "diskio_sdc.h"
#include "mmc_avr.h"
#include "ff.h"
#include "pindefs.h"

#define USE_ETHERNET
#undef DEBUG_SERIAL

#ifdef USE_ETHERNET
#include "w5500.h"
#endif

#ifdef DEBUG_SERIAL
#include <SoftwareSerial.h>
SoftwareSerial softSerial(SOFTWARE_SERIAL_RX, SOFTWARE_SERIAL_TX);
#define SERIALPORT() (&softSerial)
#endif

#define EEPROM_INIT 0
#define EEPROM_SLOT0 1
#define EEPROM_SLOT1 2

#define SLOT_STATE_NODEV 0
#define SLOT_STATE_BLOCKDEV 1
#define SLOT_STATE_WIDEDEV 2
#define SLOT_STATE_FILEDEV 3

#ifdef USE_ETHERNET
uint8_t ethernet_initialized = 0;
Wiznet5500 eth(8);
#endif

FATFS   fs;
FIL     slotfile;
uint8_t last_drive = 255;

uint8_t slot0_state = SLOT_STATE_NODEV;
uint8_t slot0_fileno;

uint8_t slot1_state = SLOT_STATE_NODEV;
uint8_t slot1_fileno;

static char blockvolzero[] = "0:";
static char blockvolone[] = "1:";

static char blockdev0_filename[] = "0:BLKDEVXX.PO";
static char blockdev1_filename[] = "1:BLKDEVXX.PO";

extern "C" {
  void write_string(const char *c)
  {
#ifdef DEBUG_SERIAL
    SERIALPORT()->print(c);
    SERIALPORT()->flush();
#endif
  }
}

void read_eeprom(void)
{
  if (EEPROM.read(EEPROM_INIT) != 255)
  {
    slot0_fileno = EEPROM.read(EEPROM_SLOT0);
    slot1_fileno = EEPROM.read(EEPROM_SLOT1);
  } else
  {
    slot0_fileno = 0;
    slot1_fileno = 1;
  }
}

void write_eeprom(void)
{
  if (EEPROM.read(EEPROM_SLOT0) != slot0_fileno)
    EEPROM.write(EEPROM_SLOT0, slot0_fileno);
  if (EEPROM.read(EEPROM_SLOT1) != slot1_fileno)
    EEPROM.write(EEPROM_SLOT1, slot1_fileno);
  if (EEPROM.read(EEPROM_INIT) == 255)
    EEPROM.write(EEPROM_INIT, 0);
}

void setup_pins(void)
{
  INITIALIZE_CONTROL_PORT();
  DISABLE_RXTX_PINS();
  DATAPORT_MODE_RECEIVE();
}

void setup_serial(void)
{
  Serial.end();
  DISABLE_RXTX_PINS();
#ifdef DEBUG_SERIAL
#ifdef SOFTWARE_SERIAL
  softSerial.begin(9600);
  pinMode(SOFTWARE_SERIAL_RX, INPUT);
  pinMode(SOFTWARE_SERIAL_TX, OUTPUT);
#endif
#endif
}

void write_dataport(uint8_t ch)
{
  while (READ_IBFA() != 0);
  DATAPORT_MODE_TRANS();
  WRITE_DATAPORT(ch);
  STB_LOW();
  STB_HIGH();
  DATAPORT_MODE_RECEIVE();
}

uint8_t read_dataport(void)
{
  uint8_t byt;

  while (READ_OBFA() != 0);
  ACK_LOW();
  byt = READ_DATAPORT();
  ACK_HIGH();
  return byt;
}

static uint8_t unit;
static uint16_t buf;
static uint16_t blk;

void get_unit_buf_blk(void)
{
  unit = read_dataport();
#ifdef DEBUG_SERIAL
  SERIALPORT()->print("0000 unit=");
  SERIALPORT()->println(unit, HEX);
#endif
  buf = read_dataport();
  buf |= (((uint16_t)read_dataport()) << 8);
#ifdef DEBUG_SERIAL
  SERIALPORT()->print("0000 buf=");
  SERIALPORT()->println(buf, HEX);
#endif
  blk = read_dataport();
  blk |= (((uint16_t)read_dataport()) << 8);
#ifdef DEBUG_SERIAL
  SERIALPORT()->print("0000 blk=");
  SERIALPORT()->println(blk, HEX);
#endif
}

uint8_t hex_digit(uint8_t ch)
{
  if (ch < 10) return ch + '0';
  return ch - 10 + 'A';
}

void set_blockdev_filename(char *blockdev_filename, uint8_t fileno)
{
  blockdev_filename[8] = hex_digit(fileno >> 4);
  blockdev_filename[9] = hex_digit(fileno & 0x0F);
}

uint8_t check_change_filesystem(uint8_t current_filesystem)
{
  if (last_drive == current_filesystem)
    return 1;

  if (last_drive < 2)
  {
    f_close(&slotfile);
    f_unmount(last_drive == 0 ? blockvolzero : blockvolone);
  }
  last_drive = 255;
  if (current_filesystem < 2)
  {
    if (f_mount(&fs, current_filesystem == 0 ? blockvolzero : blockvolone, 0) != FR_OK)
      return 0;
    if (f_open(&slotfile, current_filesystem == 0 ? blockdev0_filename : blockdev1_filename, FA_READ | FA_WRITE) != FR_OK)
    {
      f_unmount(current_filesystem == 0 ? blockvolzero : blockvolone);
      return 0;
    }
  }
  last_drive = current_filesystem;
  return 1;
}

void initialize_drive(void)
{
  if (unit & 0x80)
  {
    if (slot1_state == SLOT_STATE_NODEV)
    {
      if (slot1_fileno == 255)
      {
        if (slot0_state == SLOT_STATE_NODEV)
        {
          if (disk_initialize(0) == 0)
            slot0_state = slot1_state = SLOT_STATE_WIDEDEV;
        }
      } else if (slot1_fileno == 0)
      {
        if (disk_initialize(1) == 0)
          slot1_state = SLOT_STATE_BLOCKDEV;
      } else
      {
        check_change_filesystem(255);
        set_blockdev_filename(blockdev1_filename, slot1_fileno);
        if (check_change_filesystem(1))
          slot1_state = SLOT_STATE_FILEDEV;
      }
    }
  } else
  {
    if (slot0_state == SLOT_STATE_NODEV)
    {
      if (slot0_fileno == 255)
      {
        if (slot1_state == SLOT_STATE_NODEV)
        {
          if (disk_initialize(0) == 0)
            slot0_state = slot1_state = SLOT_STATE_WIDEDEV;
        }
      } else if (slot0_fileno == 0)
      {
        if (disk_initialize(0) == 0)
          slot0_state = SLOT_STATE_BLOCKDEV;
      } else
      {
        check_change_filesystem(255);
        set_blockdev_filename(blockdev0_filename, slot0_fileno);
        if (check_change_filesystem(0))
          slot0_state = SLOT_STATE_FILEDEV;
      }
    }
  }
}

void unmount_drive(void)
{
  if (unit & 0x80)
  {
    switch (slot1_state)
    {
      case SLOT_STATE_NODEV:
        return;
      case SLOT_STATE_WIDEDEV:
      case SLOT_STATE_BLOCKDEV:
        slot1_state = SLOT_STATE_NODEV;
        return;
      case SLOT_STATE_FILEDEV:
        check_change_filesystem(255);
        slot1_state = SLOT_STATE_NODEV;
        return;
    }
  } else
  {
    switch (slot0_state)
    {
      case SLOT_STATE_NODEV:
        return;
      case SLOT_STATE_WIDEDEV:
      case SLOT_STATE_BLOCKDEV:
        slot0_state = SLOT_STATE_NODEV;
        return;
      case SLOT_STATE_FILEDEV:
        check_change_filesystem(255);
        slot0_state = SLOT_STATE_NODEV;
        return;
    }
  }
}

uint8_t check_unit_nodev(void)
{
  if (unit & 0x80)
  {
    if (slot1_state == SLOT_STATE_NODEV)
    {
      write_dataport(0x28);
      return 0;
    }
  } else
  {
    if (slot0_state == SLOT_STATE_NODEV)
    {
      write_dataport(0x28);
      return 0;
    }
  }
  return 1;
}

void do_status(void)
{
  get_unit_buf_blk();
  if (check_unit_nodev())
    write_dataport(0x00);
}

static uint32_t blockloc;

uint32_t calculate_block_location(uint8_t voltype)
{
  uint8_t unitshift = unit & ((voltype == SLOT_STATE_WIDEDEV) ? 0xF0 : 0x70);
  blockloc = ((uint32_t)blk) | (((uint32_t)(unitshift)) << 12);
}

uint32_t calculate_file_location(void)
{
  blockloc = ((uint32_t)blk) << 9;
}

void do_read(void)
{
  UINT br;
  uint8_t buf[512];

  get_unit_buf_blk();
  if (check_unit_nodev() == 0) return;
  if (unit & 0x80)
  {
    switch (slot1_state)
    {
      case SLOT_STATE_WIDEDEV:
      case SLOT_STATE_BLOCKDEV:
        calculate_block_location(slot1_state);
        if (disk_read(slot1_state == SLOT_STATE_BLOCKDEV ? 1 : 0, buf, blockloc, 1) != 0)
        {
          write_dataport(0x27);
          return;
        }
        break;
      case SLOT_STATE_FILEDEV:
        if (!check_change_filesystem(1))
        {
          write_dataport(0x27);
          return;
        }
        calculate_file_location();
        if ((f_lseek(&slotfile, blockloc) != FR_OK) ||
            (f_read(&slotfile, buf, 512, &br) != FR_OK) ||
            (br != 512))
        {
          write_dataport(0x27);
          return;
        }
        break;
    }
  } else
  {
    switch (slot0_state)
    {
      case SLOT_STATE_WIDEDEV:
      case SLOT_STATE_BLOCKDEV:
        calculate_block_location(slot0_state);
        if (disk_read(0, buf, blockloc, 1) != 0)
        {
          write_dataport(0x27);
          return;
        }
        break;
      case SLOT_STATE_FILEDEV:
        if (!check_change_filesystem(0))
        {
          write_dataport(0x27);
          return;
        }
        calculate_file_location();
        if ((f_lseek(&slotfile, blockloc) != FR_OK) ||
            (f_read(&slotfile, buf, 512, &br) != FR_OK) ||
            (br != 512))
        {
          write_dataport(0x27);
          return;
        }
        break;
    }
  }
  write_dataport(0x00);
  DATAPORT_MODE_TRANS();
  for (uint16_t i = 0; i < 512; i++)
  {
    while (READ_IBFA() != 0);
    WRITE_DATAPORT(buf[i]);
    STB_LOW();
    STB_HIGH();
  }
  DATAPORT_MODE_RECEIVE();
}

void do_write(void)
{
  UINT br;
  uint8_t buf[512];

  get_unit_buf_blk();
  if (check_unit_nodev() == 0) return;
  write_dataport(0x00);

  for (uint16_t i = 0; i < 512; i++)
  {
    while (READ_OBFA() != 0);
    ACK_LOW();
    buf[i] = READ_DATAPORT();
    ACK_HIGH();
  }

  if (unit & 0x80)
  {
    switch (slot1_state)
    {
      case SLOT_STATE_WIDEDEV:
      case SLOT_STATE_BLOCKDEV:
        calculate_block_location(slot1_state);
        disk_write(slot1_state == SLOT_STATE_BLOCKDEV ? 1 : 0, buf, blockloc, 1);
        break;
      case SLOT_STATE_FILEDEV:
        if (!check_change_filesystem(1))
          return;
        calculate_file_location();
        if ((f_lseek(&slotfile, blockloc) != FR_OK) ||
            (f_write(&slotfile, buf, 512, &br) != FR_OK) ||
            (br != 512))
          return;
        break;
    }
  } else
  {
    switch (slot0_state)
    {
      case SLOT_STATE_WIDEDEV:
      case SLOT_STATE_BLOCKDEV:
        calculate_block_location(slot0_state);
        disk_write(0, buf, blockloc, 1);
        break;
      case SLOT_STATE_FILEDEV:
        if (!check_change_filesystem(0))
          return;
        calculate_file_location();
        if ((f_lseek(&slotfile, blockloc) != FR_OK) ||
            (f_write(&slotfile, buf, 512, &br) != FR_OK) ||
            (br != 512))
          return;
        break;
    }
  }
  return;
}

void do_format(void)
{
  get_unit_buf_blk();
  if (check_unit_nodev() == 0) return;
  write_dataport(0x00);
}

void write_zeros(uint16_t num)
{
  DATAPORT_MODE_TRANS();
  while (num > 0)
  {
    while (READ_IBFA() != 0);
    WRITE_DATAPORT(0x00);
    STB_LOW();
    STB_HIGH();
    num--;
  }
  DATAPORT_MODE_RECEIVE();
}

void do_set_volume(uint8_t cmd)
{
  get_unit_buf_blk();
  unit = 0x80;
  unmount_drive();
  unit = 0x0;
  unmount_drive();
  slot0_fileno = blk & 0xFF;
  slot1_fileno = (blk >> 8);
  if (cmd != 6) write_eeprom();
  unit = 0x80;
  initialize_drive();
  unit = 0x0;
  initialize_drive();
  write_dataport(0x00);
  if (cmd != 4) write_zeros(512);
}

void do_get_volume(void)
{
  get_unit_buf_blk();
  write_dataport(0x00);
  write_dataport(slot0_fileno);
  write_dataport(slot1_fileno);
  write_zeros(510);
}

#ifdef USE_ETHERNET
void do_initialize_ethernet(void)
{
  uint8_t mac_address[6];
#ifdef DEBUG_SERIAL
  SERIALPORT()->println("initialize ethernet");
#endif
  for (uint8_t i = 0; i < 6; i++)
  {
    mac_address[i] = read_dataport();
#ifdef DEBUG_SERIAL
    SERIALPORT()->print(mac_address[i], HEX);
    SERIALPORT()->print(" ");
#endif
  }
  if (ethernet_initialized)
    eth.end();
  if (eth.begin(mac_address))
  {
#ifdef DEBUG_SERIAL
    SERIALPORT()->println("initialized");
#endif
    ethernet_initialized = 1;
    write_dataport(0);
    return 0;
  }
#ifdef DEBUG_SERIAL
  SERIALPORT()->println("not initialized");
#endif
  ethernet_initialized = 0;
  write_dataport(1);
  return 1;
}

void do_poll_ethernet(void)
{
  uint16_t len;
#ifdef DEBUG_SERIAL
  SERIALPORT()->println("poll eth");
#endif
  if (ethernet_initialized)
  {
    len = read_dataport();
    len |= ((uint16_t)read_dataport()) << 8;
#ifdef DEBUG_SERIAL
    SERIALPORT()->print("read len ");
    SERIALPORT()->println(len, HEX);
#endif
    len = eth.readFrame(NULL, len);
#ifdef DEBUG_SERIAL
    SERIALPORT()->print("recv len ");
    SERIALPORT()->println(len, HEX);
#endif
  } else
  {
    write_dataport(0);
    write_dataport(0);
  }
}

void do_send_ethernet(void)
{
  uint16_t len;
#ifdef DEBUG_SERIAL
  SERIALPORT()->println("send eth");
#endif
  if (ethernet_initialized)
  {
    len = read_dataport();
    len |= ((uint16_t)read_dataport()) << 8;
#ifdef DEBUG_SERIAL
    SERIALPORT()->print("len ");
    SERIALPORT()->println(len, HEX);
#endif
    eth.sendFrame(NULL, len);
  }
  write_dataport(0);
}
#endif

const uint8_t bootblocks[] PROGMEM = {  
  0xea, 0xa9, 0x20, 0x85, 0xf0, 0xa9, 0x60, 0x85, 0xf3, 0xa5, 0x43, 0x4a,
  0x4a, 0x4a, 0x4a, 0x29, 0x07, 0x09, 0xc0, 0x85, 0xf2, 0xa0, 0x00, 0x84,
  0xf1, 0x88, 0xb1, 0xf1, 0x85, 0xf1, 0x20, 0x93, 0xfe, 0x20, 0x89, 0xfe,
  0x20, 0x58, 0xfc, 0x20, 0xa2, 0x09, 0xa9, 0x00, 0x85, 0x25, 0x20, 0x22,
  0xfc, 0xa5, 0x25, 0x85, 0xf5, 0x85, 0xf6, 0x20, 0x90, 0x09, 0xa9, 0x00,
  0x85, 0x24, 0xa5, 0x25, 0x20, 0xe3, 0xfd, 0xe6, 0x24, 0x20, 0x7a, 0x09,
  0x20, 0x04, 0x09, 0xa9, 0x14, 0x85, 0x24, 0xa5, 0x25, 0x20, 0xe3, 0xfd,
  0xe6, 0x24, 0xa5, 0x43, 0x09, 0x80, 0x85, 0x43, 0x20, 0x7a, 0x09, 0x20,
  0x04, 0x09, 0xa5, 0x43, 0x29, 0x7f, 0x85, 0x43, 0xe6, 0x25, 0xa5, 0x25,
  0xc9, 0x10, 0x90, 0xbe, 0xa9, 0x00, 0x85, 0x24, 0xa9, 0x12, 0x85, 0x25,
  0x20, 0x22, 0xfc, 0xa2, 0x14, 0x20, 0x66, 0x09, 0x20, 0x61, 0x09, 0xa9,
  0x0a, 0x85, 0x24, 0xa5, 0xf7, 0x20, 0xf8, 0x08, 0xa9, 0x14, 0x85, 0x24,
  0x20, 0x5c, 0x09, 0xa9, 0x1e, 0x85, 0x24, 0xa5, 0xf8, 0x20, 0xf8, 0x08,
  0xa9, 0x0a, 0x85, 0x24, 0x20, 0xca, 0x08, 0x85, 0xf5, 0x20, 0xf8, 0x08,
  0xa9, 0x1e, 0x85, 0x24, 0x20, 0xca, 0x08, 0x85, 0xf6, 0x20, 0xf8, 0x08,
  0x20, 0x8c, 0x09, 0x4c, 0xb7, 0x09, 0xa5, 0xf7, 0x85, 0xf5, 0xa5, 0xf8,
  0x85, 0xf6, 0x20, 0x90, 0x09, 0x68, 0x68, 0x4c, 0xb7, 0x09, 0x20, 0x0c,
  0xfd, 0xc9, 0x9b, 0xf0, 0xe9, 0xc9, 0xa1, 0xf0, 0x20, 0xc9, 0xe1, 0x90,
  0x03, 0x38, 0xe9, 0x20, 0xc9, 0xc1, 0x90, 0x04, 0xc9, 0xc7, 0x90, 0x0b,
  0xc9, 0xb0, 0x90, 0xe2, 0xc9, 0xba, 0xb0, 0xde, 0x29, 0x0f, 0x60, 0x38,
  0xe9, 0x07, 0x29, 0x0f, 0x60, 0xa9, 0xff, 0x60, 0xc9, 0xff, 0xf0, 0x03,
  0x4c, 0xe3, 0xfd, 0xa9, 0xa1, 0x4c, 0xed, 0xfd, 0xa2, 0x00, 0xb0, 0x25,
  0xad, 0x05, 0x10, 0x30, 0x20, 0xad, 0x04, 0x10, 0x29, 0xf0, 0xc9, 0xf0,
  0xd0, 0x17, 0xad, 0x04, 0x10, 0x29, 0x0f, 0xf0, 0x10, 0x85, 0xf9, 0xbd,
  0x05, 0x10, 0x09, 0x80, 0x20, 0xed, 0xfd, 0xe8, 0xe4, 0xf9, 0xd0, 0xf3,
  0x60, 0x4c, 0x66, 0x09, 0xbc, 0xce, 0xcf, 0xa0, 0xd6, 0xcf, 0xcc, 0xd5,
  0xcd, 0xc5, 0xbe, 0x00, 0xc3, 0xc1, 0xd2, 0xc4, 0xa0, 0xb1, 0xba, 0x00,
  0xc4, 0xc1, 0xce, 0xa0, 0xdd, 0xdb, 0xa0, 0xd6, 0xcf, 0xcc, 0xd5, 0xcd,
  0xc5, 0xa0, 0xd3, 0xc5, 0xcc, 0xc5, 0xc3, 0xd4, 0xcf, 0xd2, 0x8d, 0x00,
  0xa9, 0xb2, 0x8d, 0x41, 0x09, 0xa2, 0x0c, 0x4c, 0x66, 0x09, 0xbd, 0x30,
  0x09, 0xf0, 0x0e, 0x20, 0xed, 0xfd, 0xe8, 0xd0, 0xf5, 0xa9, 0x00, 0x85,
  0x44, 0xa9, 0x10, 0x85, 0x45, 0x60, 0xa9, 0x01, 0x85, 0x42, 0x20, 0x71,
  0x09, 0xa9, 0x02, 0x85, 0x46, 0xa9, 0x00, 0x85, 0x47, 0x4c, 0xf0, 0x00,
  0xa9, 0x07, 0xd0, 0x02, 0xa9, 0x06, 0x85, 0x42, 0x20, 0x71, 0x09, 0xa5,
  0xf5, 0x85, 0x46, 0xa5, 0xf6, 0x85, 0x47, 0x4c, 0xf0, 0x00, 0xa9, 0x05,
  0x85, 0x42, 0x20, 0x71, 0x09, 0x20, 0xf0, 0x00, 0xad, 0x00, 0x10, 0x85,
  0xf7, 0xad, 0x01, 0x10, 0x85, 0xf8, 0x60, 0xa9, 0x00, 0x85, 0xf1, 0x6c,
  0xf1, 0x00
};  

#define NUMBER_BOOTBLOCKS (sizeof(bootblocks)/(512*sizeof(uint8_t)))

void do_send_bootblock()
{
  get_unit_buf_blk();
  write_dataport(0x00);
  if (blk >= NUMBER_BOOTBLOCKS) blk = 0;
  blk <<= 9;
  DATAPORT_MODE_TRANS();
  for (uint16_t i = 0; i < 512; i++)
  {
    while (READ_IBFA() != 0);
    WRITE_DATAPORT(pgm_read_byte(&bootblocks[blk + i]));
    STB_LOW();
    STB_HIGH();
  }
  DATAPORT_MODE_RECEIVE();
}

void do_command()
{
  uint8_t cmd = read_dataport();
#ifdef DEBUG_SERIAL
  SERIALPORT()->print("0000 cmd=");
  SERIALPORT()->println(cmd, HEX);
#endif
  switch (cmd)
  {
    case 0:    do_status();
      break;
    case 1:    do_read();
      break;
    case 2:    do_write();
      break;
    case 3:    do_format();
      break;
    case 4:
    case 6:
    case 7:    do_set_volume(cmd);
      break;
    case 5:    do_get_volume();
      break;
#ifdef USE_ETHERNET
    case 0x10: do_initialize_ethernet();
      break;
    case 0x11: do_poll_ethernet();
      break;
    case 0x12: do_send_ethernet();
      break;
#endif
    case 13+128:
    case 32+128:  do_send_bootblock();
      break;
    default:      write_dataport(0x27);
      break;
  }
}

int freeRam ()
{
  extern int __heap_start, *__brkval;
  int v;
  return (int) &v - (__brkval == 0 ? (int) &__heap_start : (int) __brkval);
}

void setup()
{
  setup_pins();
  setup_serial();
  read_eeprom();

  unit = 0;
  initialize_drive();
  unit = 0x80;
  initialize_drive();

#ifdef DEBUG_SERIAL
  SERIALPORT()->println("0000");
  SERIALPORT()->print("d=");
  SERIALPORT()->print(sizeof(fs));
  SERIALPORT()->print(" f=");
  SERIALPORT()->print(freeRam());
  SERIALPORT()->print(" s=");
  SERIALPORT()->print(slot0_state);
  SERIALPORT()->print(" ");
  SERIALPORT()->println(slot1_state);
  SERIALPORT()->flush();
#endif

  DATAPORT_MODE_RECEIVE();
}

void loop()
{
  uint8_t instr = read_dataport();
  if (instr == 0xAC) do_command();
}

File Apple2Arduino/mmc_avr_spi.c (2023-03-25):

/*-----------------------------------------------------------------------*/
/* MMCv3/SDv1/SDv2 Controls via AVR SPI module                           */
/*-----------------------------------------------------------------------*/
/*
/  Copyright (C) 2016, ChaN, all right reserved.
/
/ * This software is a free software and there is NO WARRANTY.
/ * No restriction on use. You can use, modify and redistribute it for
/   any purpose as you like UNDER YOUR RESPONSIBILITY.
/ * Redistributions of source code must retain the above copyright notice.
/
/-------------------------------------------------------------------------*/

#include <Arduino.h>
#include <avr/io.h>
#include "diskio_sdc.h"
#include "mmc_avr.h"
#include "pindefs.h"

/* Peripheral controls (Platform dependent) */
#define CS_LOW()		do { PORTB &= (slotno ?  ~0x02 : ~0x04); } while (0) /* Set MMC_CS = low */
#define	CS_HIGH()		do { PORTB |= 0x07; } while (0) /* Set MMC_CS = high */
#define MMC_CD			(1)	/* Test if card detected.   yes:true, no:false, default:true */
#define MMC_WP			(0)	/* Test if write protected. yes:true, no:false, default:false */
#define	FCLK_SLOW()		do { SPCR |= (_BV(SPR0)|_BV(SPR1)); } while (0)	/* Set SPI clock for initialization (100-400kHz) */
#define	FCLK_FAST()		do { SPCR &= ~(_BV(SPR0)|_BV(SPR1)); } while (0)	/* Set SPI clock for read/write (20MHz max) */
#define PULLUP_OFF()    do { PORTB &= ~0x10; } while (0) 
#define PULLUP_ON()     do { PORTB |= 0x10; } while (0) 


/*--------------------------------------------------------------------------

   Module Private Functions

---------------------------------------------------------------------------*/

/* Definitions for MMC/SDC command */
#define CMD0	(0)			/* GO_IDLE_STATE */
#define CMD1	(1)			/* SEND_OP_COND (MMC) */
#define	ACMD41	(0x80+41)	/* SEND_OP_COND (SDC) */
#define CMD8	(8)			/* SEND_IF_COND */
#define CMD9	(9)			/* SEND_CSD */
#define CMD10	(10)		/* SEND_CID */
#define CMD12	(12)		/* STOP_TRANSMISSION */
#define ACMD13	(0x80+13)	/* SD_STATUS (SDC) */
#define CMD16	(16)		/* SET_BLOCKLEN */
#define CMD17	(17)		/* READ_SINGLE_BLOCK */
#define CMD18	(18)		/* READ_MULTIPLE_BLOCK */
#define CMD23	(23)		/* SET_BLOCK_COUNT (MMC) */
#define	ACMD23	(0x80+23)	/* SET_WR_BLK_ERASE_COUNT (SDC) */
#define CMD24	(24)		/* WRITE_BLOCK */
#define CMD25	(25)		/* WRITE_MULTIPLE_BLOCK */
#define CMD32	(32)		/* ERASE_ER_BLK_START */
#define CMD33	(33)		/* ERASE_ER_BLK_END */
#define CMD38	(38)		/* ERASE */
#define	CMD48	(48)		/* READ_EXTR_SINGLE */
#define	CMD49	(49)		/* WRITE_EXTR_SINGLE */
#define CMD55	(55)		/* APP_CMD */
#define CMD58	(58)		/* READ_OCR */


static volatile DSTATUS Stat[2] = { STA_NOINIT, STA_NOINIT };	/* Disk status */
static BYTE CardType[2];			/* Card type flags (b0:MMC, b1:SDv1, b2:SDv2, b3:Block addressing) */

BYTE slotno = 0;

/*-----------------------------------------------------------------------*/
/* Power Control  (Platform dependent)                                   */
/*-----------------------------------------------------------------------*/
/* When the target system does not support socket power control, there   */
/* is nothing to do in these functions and chk_power always returns 1.   */

static
void power_on (void)
{
	cli();
  PORTB = 0x07;
	DDRB |= 0x07;
	PORTB = 0x07;
	SPCR = _BV(SPE) | _BV(MSTR);
	SPSR = _BV(SPI2X);
	DDRB |= 0x2F;
	PORTB = 0x3F;
	sei(); 
}

static
void power_off (void)
{
#if 0
	cli();
	SPCR = 0;
	DDRB &= ~0x3F;
	sei(); 
#endif
}

/*-----------------------------------------------------------------------*/
/* Transmit/Receive data from/to MMC via SPI  (Platform dependent)       */
/*-----------------------------------------------------------------------*/

/* Exchange a byte */
static
BYTE xchg_spi (		/* Returns received data */
	BYTE dat		/* Data to be sent */
)
{
	SPDR = dat;
	loop_until_bit_is_set(SPSR, SPIF);
	return SPDR;
}


/* Receive a data block fast */
static
void rcvr_spi_multi (
	BYTE *p,	/* Data read buffer */
	UINT cnt	/* Size of data block */
)
{
	do {
		SPDR = 0xFF;
		loop_until_bit_is_set(SPSR, SPIF);
		*p++ = SPDR;
		SPDR = 0xFF;
		loop_until_bit_is_set(SPSR, SPIF);
		*p++ = SPDR;
	} while (cnt -= 2);
}


/* Send a data block fast */
static
void xmit_spi_multi (
	const BYTE *p,	/* Data block to be sent */
	UINT cnt		/* Size of data block */
)
{
	do {
		SPDR = *p++;
		loop_until_bit_is_set(SPSR, SPIF);
		SPDR = *p++;
		loop_until_bit_is_set(SPSR, SPIF);
	} while (cnt -= 2);
}



/*-----------------------------------------------------------------------*/
/* Wait for card ready                                                   */
/*-----------------------------------------------------------------------*/

static
int wait_ready (	/* 1:Ready, 0:Timeout */
	UINT wt			/* Timeout [ms] */
)
{
	BYTE d;
  uint16_t intime;

	intime = millis();
	do {
		d = xchg_spi(0xFF);
	} while (d != 0xFF && (((int16_t)(((uint16_t)millis())-intime)) < wt));

	return (d == 0xFF) ? 1 : 0;
}



/*-----------------------------------------------------------------------*/
/* Deselect the card and release SPI bus                                 */
/*-----------------------------------------------------------------------*/

static
void deselect (void)
{
	CS_HIGH();		/* Set CS# high */
	xchg_spi(0xFF);	/* Dummy clock (force DO hi-z for multiple slave SPI) */
}



/*-----------------------------------------------------------------------*/
/* Select the card and wait for ready                                    */
/*-----------------------------------------------------------------------*/

static
int select (void)	/* 1:Successful, 0:Timeout */
{
	CS_LOW();		/* Set CS# low */
	xchg_spi(0xFF);	/* Dummy clock (force DO enabled) */

	if (wait_ready(500)) return 1;	/* Leading busy check: Wait for card ready */

	deselect();		/* Timeout */
	return 0;
}



/*-----------------------------------------------------------------------*/
/* Receive a data packet from MMC                                        */
/*-----------------------------------------------------------------------*/

static
int rcvr_datablock (
	BYTE *buff,			/* Data buffer to store received data */
	UINT btr			/* Byte count (must be multiple of 4) */
)
{
	BYTE token;

    uint16_t intime = millis();
	
	do {							/* Wait for data packet in timeout of 200ms */
		token = xchg_spi(0xFF);
	} while ((token == 0xFF) && (((int16_t)(((uint16_t)millis())-intime)) < 200));
	if (token != 0xFE) return 0;	/* If not valid data token, retutn with error */

	rcvr_spi_multi(buff, btr);		/* Receive the data block into buffer */
	xchg_spi(0xFF);					/* Discard CRC */
	xchg_spi(0xFF);

	return 1;						/* Return with success */
}



/*-----------------------------------------------------------------------*/
/* Send a data packet to MMC                                             */
/*-----------------------------------------------------------------------*/
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

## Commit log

2022-05-25 Swapped OR with AND
    [Apple2Card.kicad_pcb, Apple2Card.kicad_sch]
2022-05-26 Add power supply bypass jumpers for power supply variations
2022-05-26 try committing again
    [Apple2Card-B_Cu.gbr, Apple2Card-B_Mask.gbr, Apple2Card-B_Silkscreen.gbr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]
2022-05-27 Before changing to 8255
    [Apple2Card-B_Cu.gbr, Apple2Card-B_Mask.gbr, Apple2Card-B_Silkscreen.gbr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]
2022-05-27 Changed to 8255
    [Apple2Card-B_Cu.gbr, Apple2Card-B_Mask.gbr, Apple2Card-B_Silkscreen.gbr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]
2022-05-28 Added ROM banking
    [Apple2Card-B_Cu.gbr, Apple2Card-B_Mask.gbr, Apple2Card-B_Silkscreen.gbr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]
2022-05-29 Before combining connectors
    [Apple2Card.kicad_pcb]
2022-05-30 Added initial boot firmware
    [Apple2Card-B_Cu.gbr, Apple2Card-B_Mask.gbr, Apple2Card-B_Silkscreen.gbr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]
2022-06-01 Initial commit of Arduino sketch
    [Apple2Card-B_Cu.gbr, Apple2Card-B_Mask.gbr, Apple2Card-B_Silkscreen.gbr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]
2022-06-02 Added w5500 driver
2022-06-03 Fixed memory overallocation problem in Arduinosketch
    [Apple2Card-B_Cu.gbr, Apple2Card-B_Mask.gbr, Apple2Card-B_Silkscreen.gbr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]
2022-06-04 Fixed reset circuitry
    [Apple2Card-B_Cu.gbr, Apple2Card-B_Mask.gbr, Apple2Card-B_Silkscreen.gbr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]
2022-06-07 Added code to firmware for bank select
    [Apple2Card-B_Cu.gbr, Apple2Card-B_Mask.gbr, Apple2Card-B_Silkscreen.gbr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]
2022-06-09 Both slots working with real hardwarE
    [Apple2Card-B_Cu.gbr, Apple2Card-B_Mask.gbr, Apple2Card-B_Silkscreen.gbr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]
2022-06-09 Fixed device select timing bug
    [Apple2Card-B_Cu.gbr, Apple2Card-B_Mask.gbr, Apple2Card-B_Silkscreen.gbr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]
2022-06-12 Cards and storage works!
    [Apple2Card-B_Cu.gbr, Apple2Card-B_Mask.gbr, Apple2Card-B_Silkscreen.gbr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]
2022-06-12 Tweaked edges
    [Apple2Card-B_Cu.gbr, Apple2Card-B_Mask.gbr, Apple2Card-B_Silkscreen.gbr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]
2022-06-13 Added important message
    [Apple2Card.kicad_pcb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]
2022-06-13 Added programming jumper
    [Apple2Card-B_Cu.gbr, Apple2Card-B_Mask.gbr, Apple2Card-B_Silkscreen.gbr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]
2022-06-13 Added other connections to 28C256 address lines
    [Apple2Card-B_Cu.gbr, Apple2Card-B_Mask.gbr, Apple2Card-B_Silkscreen.gbr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]
2022-06-15 JLCPCB order 2022-06-15
    [Apple2Card-B_Cu.gbr, Apple2Card-B_Mask.gbr, Apple2Card-B_Silkscreen.gbr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]
2022-06-17 Switched around Ethernet output to front side of card, and added access LED for storage
    [Apple2Card-B_Cu.gbr, Apple2Card-B_Mask.gbr, Apple2Card-B_Silkscreen.gbr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]
2022-06-23 Added CS/CS2 pins to feature connector
    [Apple2Card-B_Cu.gbr, Apple2Card-B_Mask.gbr, Apple2Card-B_Silkscreen.gbr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]
2022-06-24 Added picture
    [Apple2Card.kicad_sch]
2022-06-25 Changed pull-down resistor values
    [Apple2Card.kicad_sch]
2022-06-27 Don't turn off SPI
2022-07-26 Fixed firmware to work with total replay
    [Apple2Card-B_Cu.gbr, Apple2Card-B_Mask.gbr, Apple2Card-B_Silkscreen.gbr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]
2022-08-05 oops driver number wrong in allvols
2022-08-14 Added Ethernet Mount Object
    [EthernetCover-EthernetMount.stl, EthernetCover.FCStd]
2022-11-18 Added ESC for boot continue, SPACE for alternate boot sector
2022-11-21 Add Makefile and fuses.cfg for command-line firmware creation / burning.
    [fuses.cfg]
2022-11-22 Fixed get status command
    [Apple2Arduino.ino]
2022-11-22 Bug in get status/set status
    [Apple2Arduino.ino]
2022-11-22 Fixed status yet again...
    [Apple2Arduino.ino]
2022-11-23 First draft of volume selection page in Arduino
2022-11-27 Got rid of debugging unit fix and added IN#0/PR#0 to bootpg
    [Apple2Arduino.ino]
2022-12-09 Support both old and new minipro fuse syntax.
    [fuses.cfg]
2023-03-24 Improved SD-card compatibility (and performance)
    1. Compatibility fix for some SD cards
    After a power-down an SD card will always immediately respond to CMD0
    ("GO IDLE" command) with "1" ("in idle state"). However, since this controller
    hardware does not support physical power-down/reset, a card which was already
    initialized may also respond to CMD0 with "0" (=not idle (yet)), if it's still
    busy. In this case we need to briefly wait and poll the state again, until
    the SD card is indeed idle.
    This fixes a compatibility issue with some SDHC cards (e.g.
    "Intenso SDHC class 4" and likely other brands using the same SD core).
    2. Performance improvement
    The 100ms init delay after calling "power_o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
    [mmc_avr_spi.c]
